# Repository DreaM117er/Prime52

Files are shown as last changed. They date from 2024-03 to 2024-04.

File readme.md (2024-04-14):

# Prime52 v1

- 中文說明（Chinese Readme）。
- [英文說明（English Readme）](readme_en.md)。

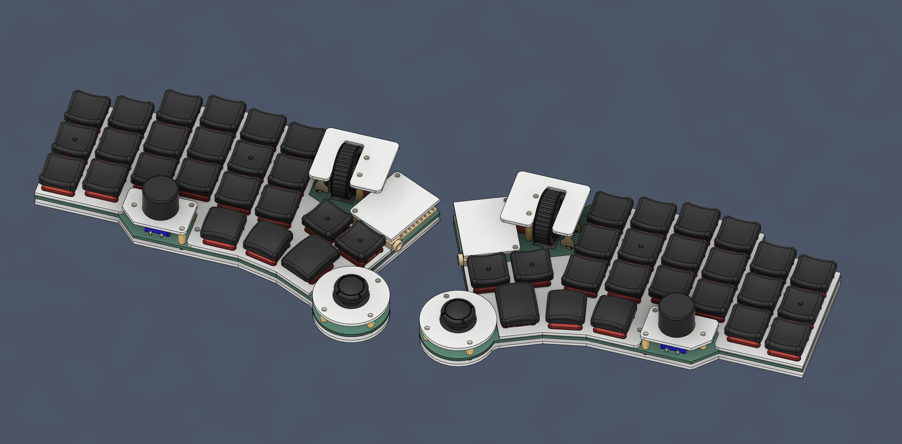
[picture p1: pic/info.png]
info
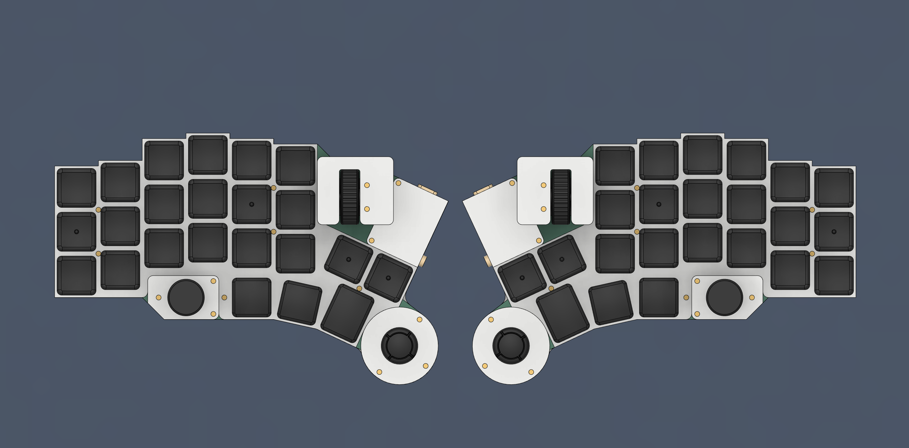
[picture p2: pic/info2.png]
info
|||
|--|--|
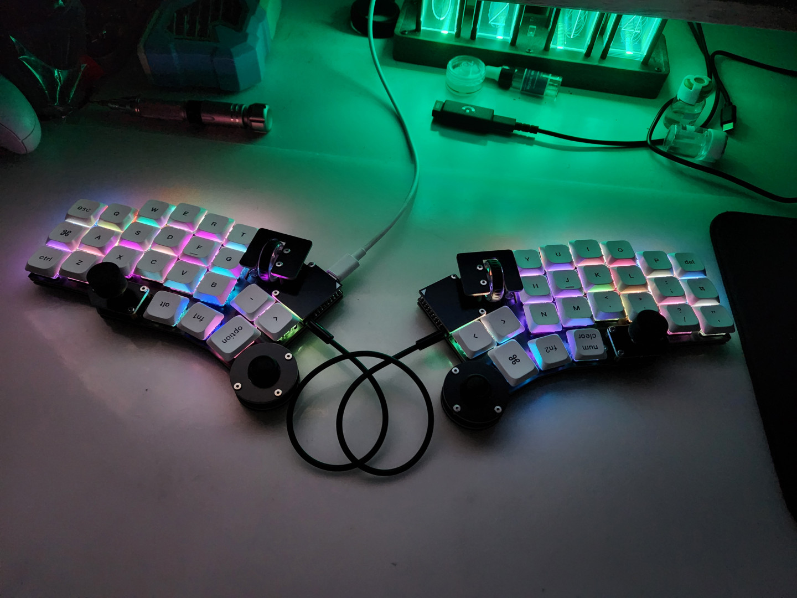
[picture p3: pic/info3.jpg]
info
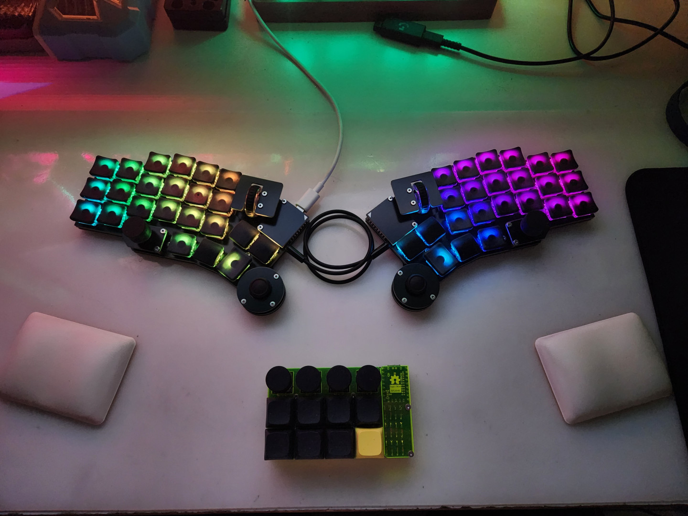
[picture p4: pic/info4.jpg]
info
|||

## 詳細說明

一直到現在為止，我還是無法適應軌跡球...

我個人沒有辦法去適應軌跡球的移動模式，更不用說要用什麼方式去操作它，因此在我將探索者1號設計出來的當下，我就知道還有一個將遊戲搖桿（Joystick）加進鍵盤內的構想在，也確實也有不少前輩設計出來，比如Dactyl Manuform Skeleton Edition的完整STL模型中，就有搖桿的存在。但礙於當時的我沒有足夠地了解3D建模及QMK韌體，一直到現在才有能力將這個很久以前就一直深埋在內心的夢想付諸實行。

它叫做Prime52，很簡單直接地說，它就是搭載Joy-con搖桿、EC-11旋轉編碼器及滑鼠滾輪的一把矮軸鍵盤，支援Choc v1、v2熱插拔。

## 使用材料

|名稱|數量|備註|連結|
|--|--|--|--|
|PCB|1|左、右|-|
|FR4外殼|2|含擋板|-|
|`RP2040Supermini`|2|-|[Link](https://www.aliexpress.com/item/1005006096780891.html?channel=twinner)|
|`EC-11`旋鈕編碼器|2|高`15mm`|[Link](https://www.aliexpress.com/item/1005006104167148.html?channel=twinner)| 
|`EC-11`編碼器帽蓋|2|`可選配`，有提供3D模型|-|
|`EC10E`滑鼠編碼器|2|高`11mm`|[Link](https://www.aliexpress.com/item/1005006279296138.html?channel=twinner)|
|`MR-0017`滑鼠滾輪|2|`可選配`，有提供3D模型|[Link](https://www.aliexpress.com/item/1005005878223914.html?channel=twinner)|
|`Joy-con`搖桿|2|`6pin`直插式|[Link](https://vi.aliexpress.com/item/1005006061159473.html)|
|`3.5mm` TRRS座|2|`4Pin`直插式|[Link](https://vi.aliexpress.com/item/1005003299392377.html?channel=twinner)|
|M2x`4mm` 雙通銅柱|12|定位板用|-|
|M2x`6mm` 雙通銅柱|6|搖桿用|-|
|M2x`7mm` 雙通銅柱|10|擋板用|-|
|M2x`15mm` 雙通銅柱|4|滑鼠滾輪用|-|
|M2x`3mm` 扁頭螺絲|48|-|-|
|M2x`8mm` 扁頭螺絲|16|-|-|
|`M2` 螺母|16|-|-|
|`M2` 防滑墊片|16||-|
|`ø8x1.5mm` 自黏腳貼|-|-|-|
|滑鼠用`微動開關`|2|-|[Link](https://vi.aliexpress.com/w/wholesale-mouse-switch.html?spm=a2g0o.productlist.search.0)|
|二極體 `1N4148`|52|貼片式 `SOD-123`|-|
|凱華`Choc`規格鍵軸|46|支援v1、v2|-|
|凱華`Choc`系列熱插拔座|46|-|[Link](https://vi.aliexpress.com/item/1005003879769486.html?channel=twinner)|
|`SK6212Mini-E` 反向LED燈|46|`選配`|[Link](https://vi.aliexpress.com/item/1005005956813491.html?channel=twinner)|

> **Note**
>
> 組裝鍵盤前務必先將韌體刷入MCU中，便測試及安裝方面會比較輕鬆容易：[點我進入組裝說明](guide.md)

## 現階段版本問題點

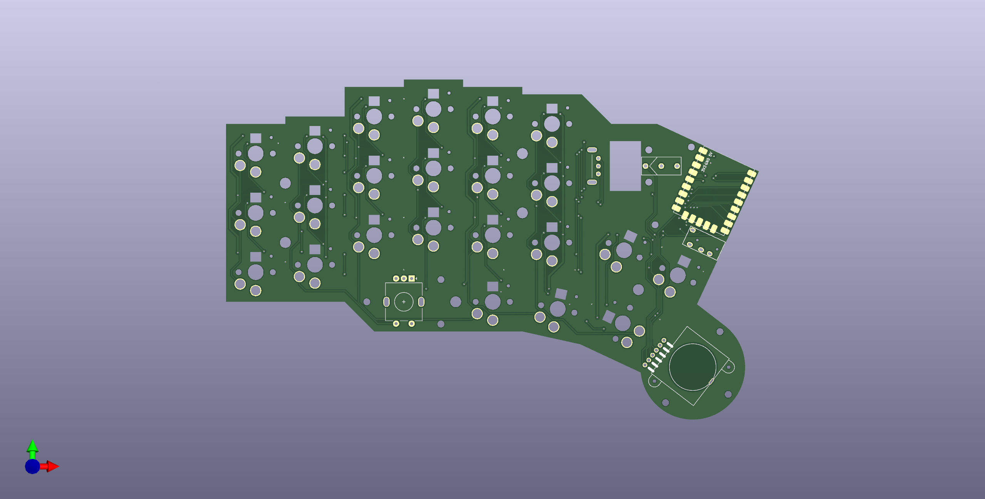
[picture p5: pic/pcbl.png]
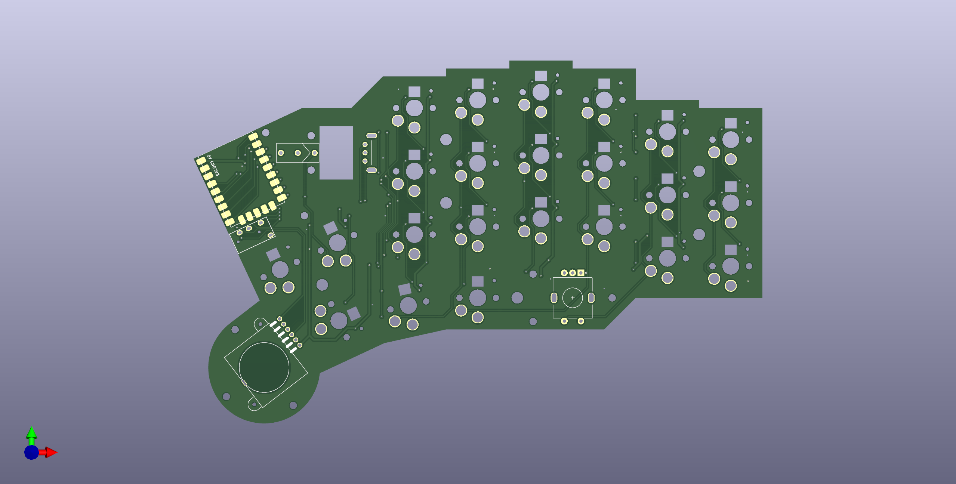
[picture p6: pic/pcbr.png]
|||
|--|--|
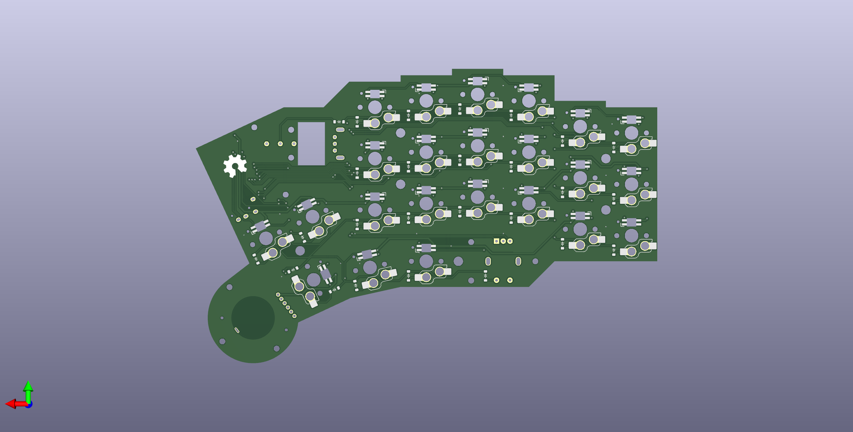
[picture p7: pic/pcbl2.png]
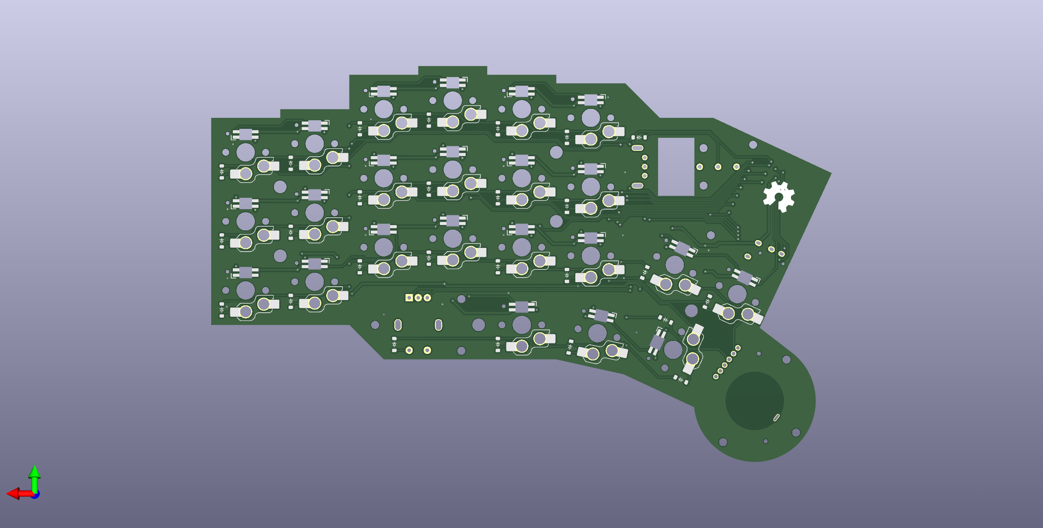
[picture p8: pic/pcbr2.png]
|||

- 滑鼠滾輪安裝上的困難，未來改進有無按鍵雙支援。
- 滑鼠編碼器的脈衝問題（暫時無法解決）。
- MCU的侷限性，未來可以支援更多類型的MCU，往大眾常使用的為主。
- 電路板的走線問題，也是無法支援更多MCU的主因。
- Slave端搖桿電位漂移、LED燈訊號有時而不穩定，有可能會開發新的鍵盤直接改掉這些問題。
- 看似對稱，但無法設計成對稱（Joy-con搖桿的主因）。

這是實際到手的`v1`版本在組裝上遇到的問題，`v2`版本的PCB會解決這個問題，並且會開發`MX`及`GLP`的版本出來。

## 使用資源

- Datasheets from TTC, ALPS, Huano.
- [QMK Firmware](https://qmk.fm/).
- [VIAL](https://get.vial.today/).
- [KiCAD](https://www.kicad.org/) version `7.0.5.`
- [JLCPCB](https://jlcpcb.com/).
- [DeepL](https://www.deepl.com/translator).
- [AutoDesk Fusion](https://www.autodesk.com/products/fusion-360/free-trial).

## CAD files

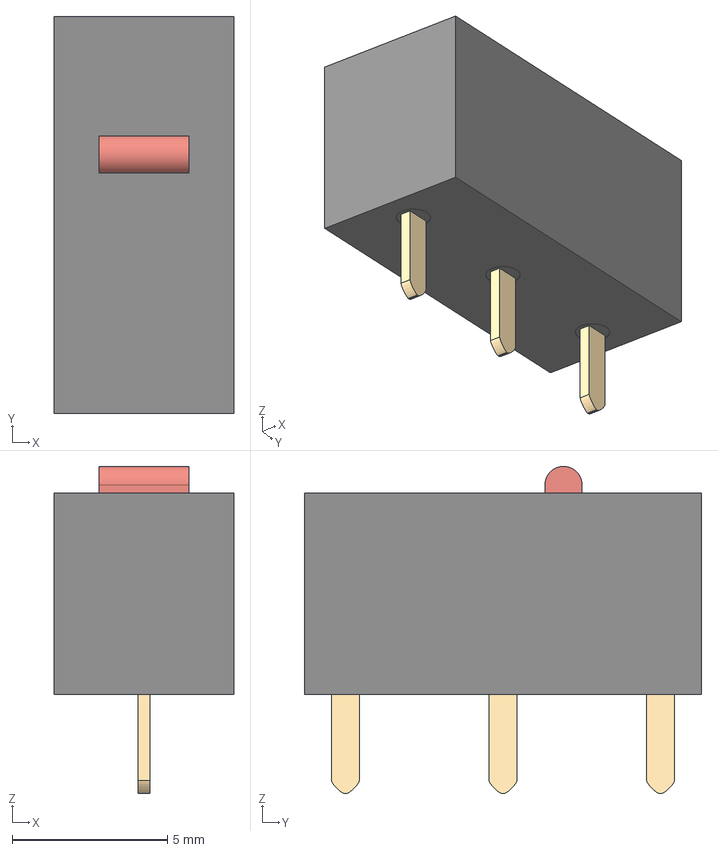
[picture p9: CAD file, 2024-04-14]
file/3d model/mouse micro switch.step
5.80 x 12.8 x 10.6 mm

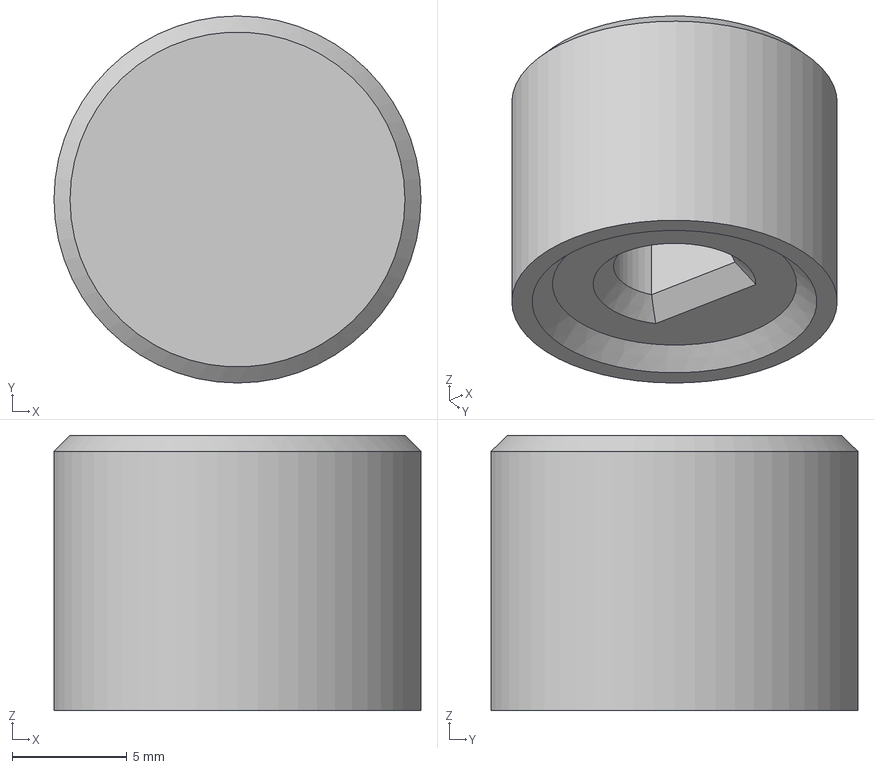
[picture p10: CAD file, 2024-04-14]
file/3d model/type-d h7.0mm.step
16.0 x 16.0 x 12.0 mm

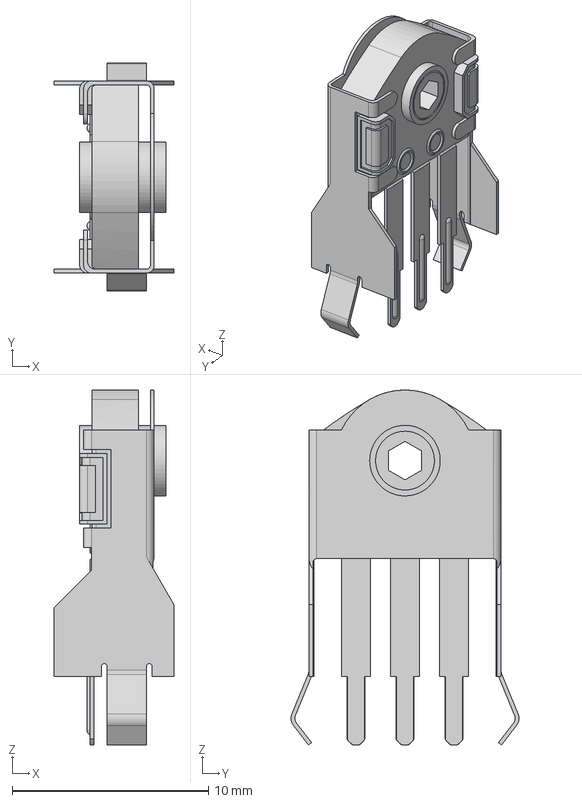
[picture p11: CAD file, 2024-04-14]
file/3d model/mouse encoder h11.step
6.10 x 11.6 x 18.1 mm

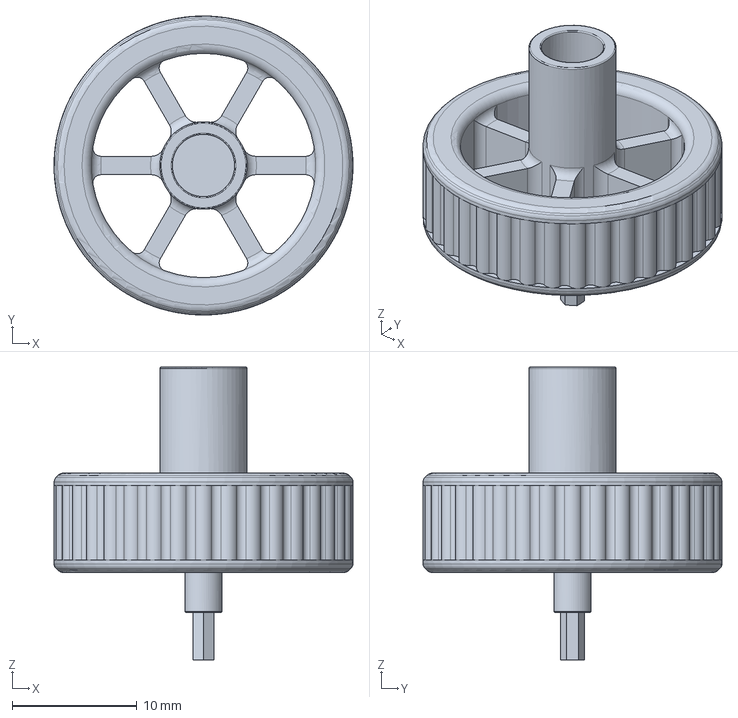
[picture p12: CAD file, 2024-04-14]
file/3d model/mousewheel MR0017 detail.step
24.0 x 24.0 x 23.5 mm

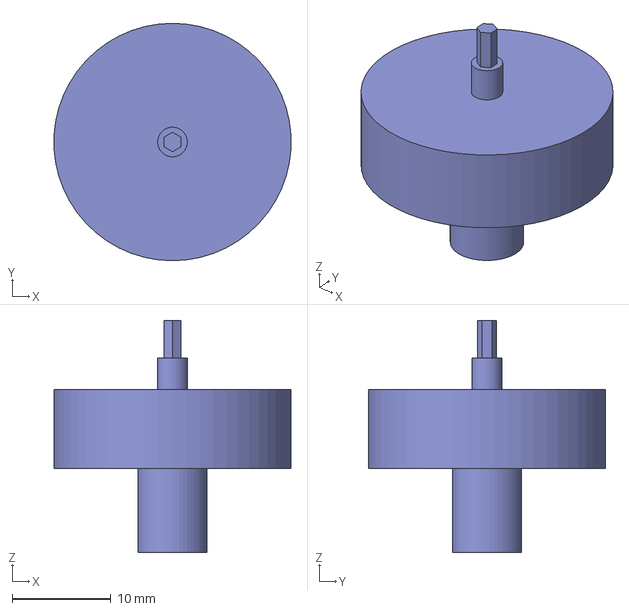
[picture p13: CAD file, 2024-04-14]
file/3d model/mousewheel MR0017 prototype.step
24.0 x 24.0 x 23.5 mm

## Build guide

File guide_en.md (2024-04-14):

# Building Guide

- [中文版本（Chinese Readme）](guide.md)。
- 英文版本（English Readme）。

## Firmware

> **Note**
>
> The firmware programming method of RP2040 series is more or less the same, no matter whether it is the version of MCU with Reset and Bootloader dual buttons or not, all of them have the same programming method.

- Press and hold the Bootloader button and then connect to the computer, the local computer will show you the location of the hard drive where the firmware is burned.
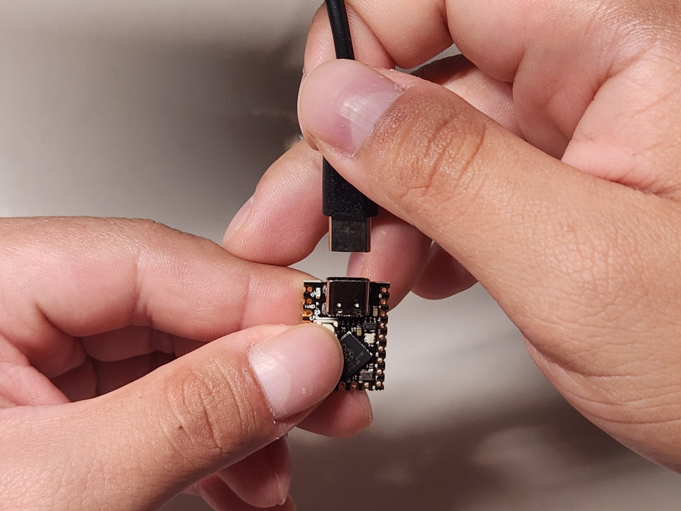
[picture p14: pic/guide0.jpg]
guide


- Then move the .uf2 firmware file to the hard drive to finish flashing.
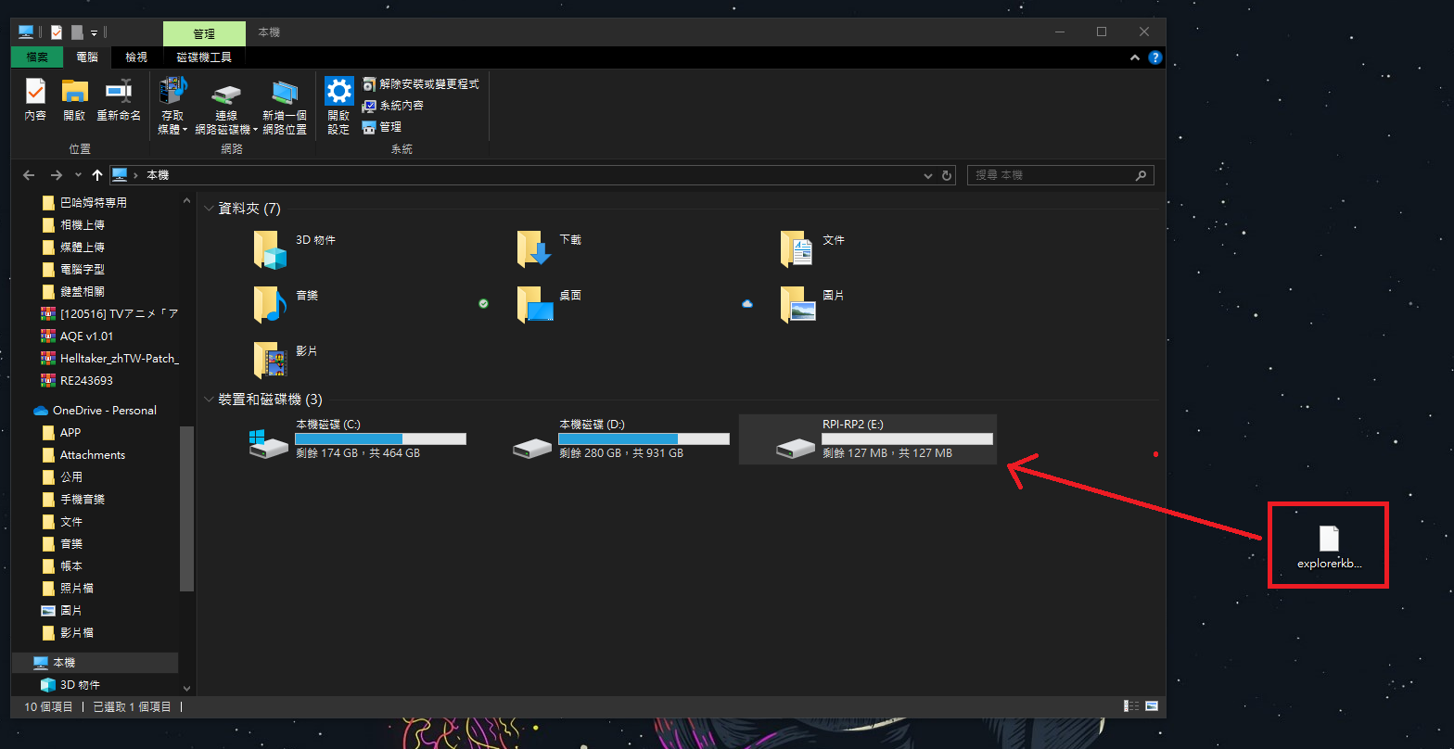
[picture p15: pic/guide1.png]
guide


## PCB and MCU

- First of all, prepare the two MCU and the left and right PCBs.
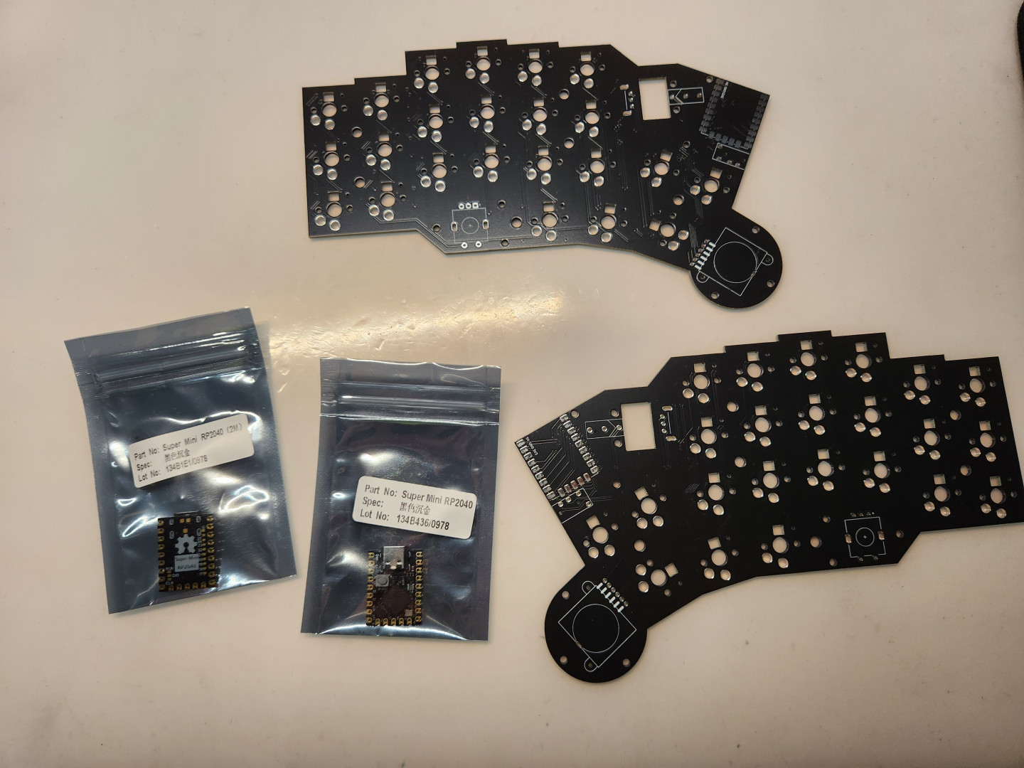
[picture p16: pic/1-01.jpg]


- Cut a piece of paper tape and fix the MCU with the tape in the right position.
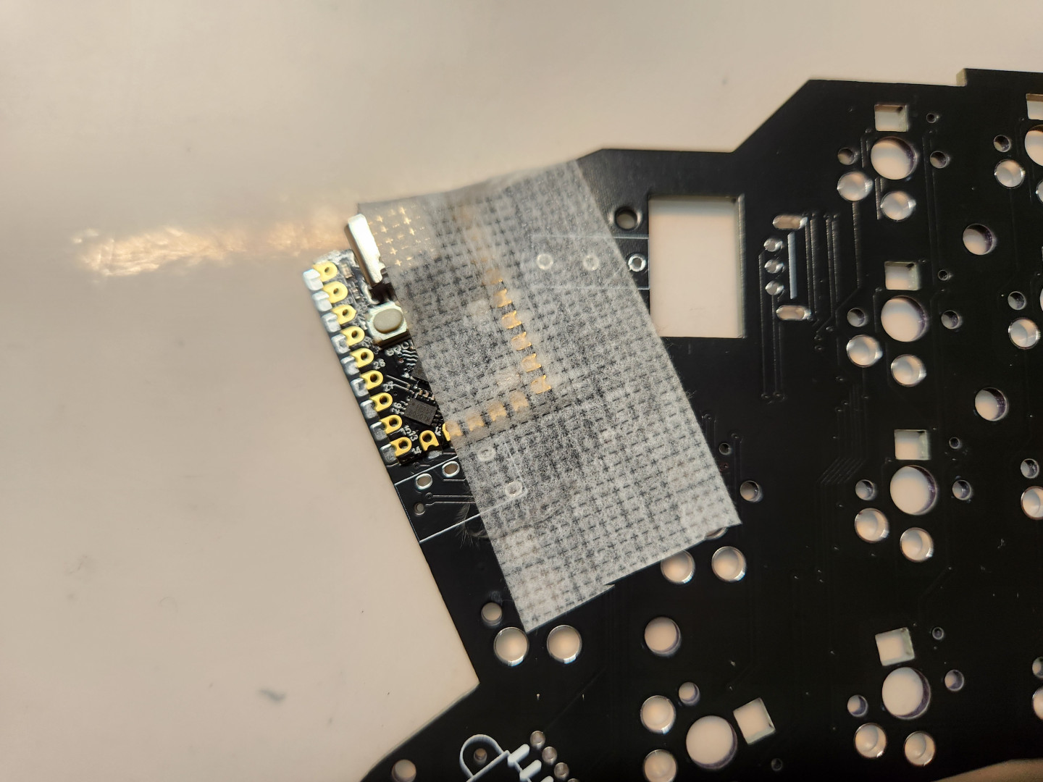
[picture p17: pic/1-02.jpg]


- Fix one of the rows of pads with solder first, and then tear off the tape.
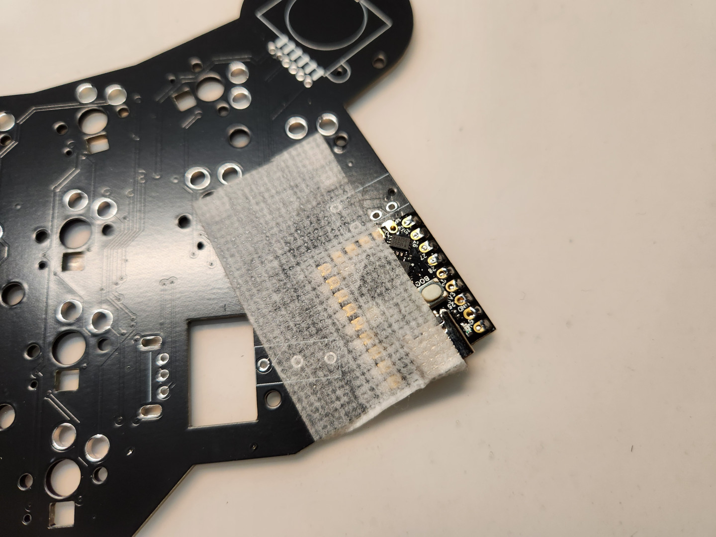
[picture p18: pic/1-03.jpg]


- Then use solder to attach the pads at the other locations.
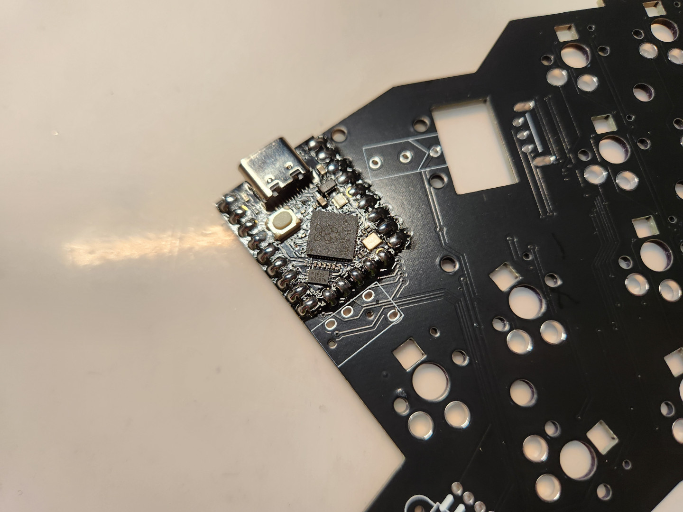
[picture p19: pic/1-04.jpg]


## SMD Parts

- Please refer to the picture for the mounting method of 1N4148 diode.
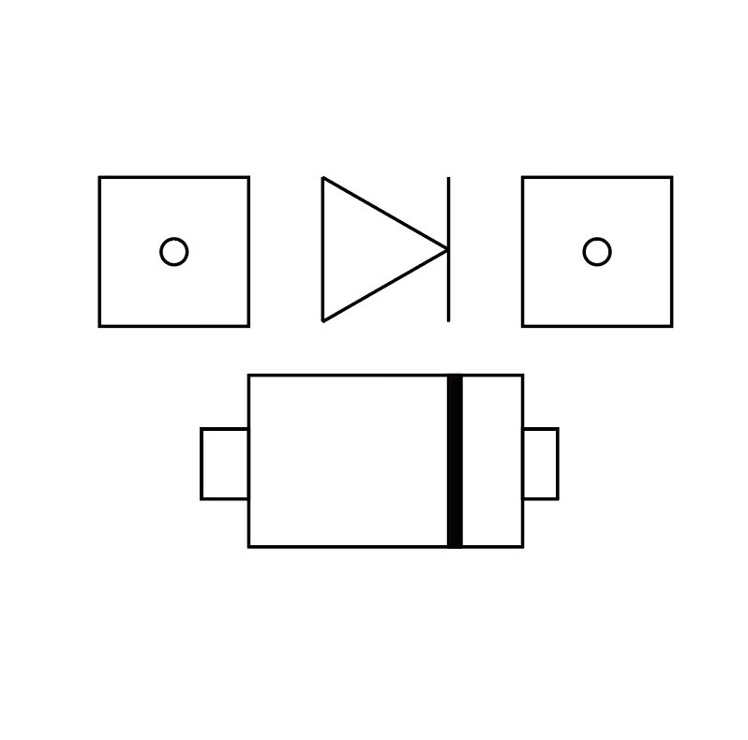
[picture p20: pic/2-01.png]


- Solder the 52 diodes together.
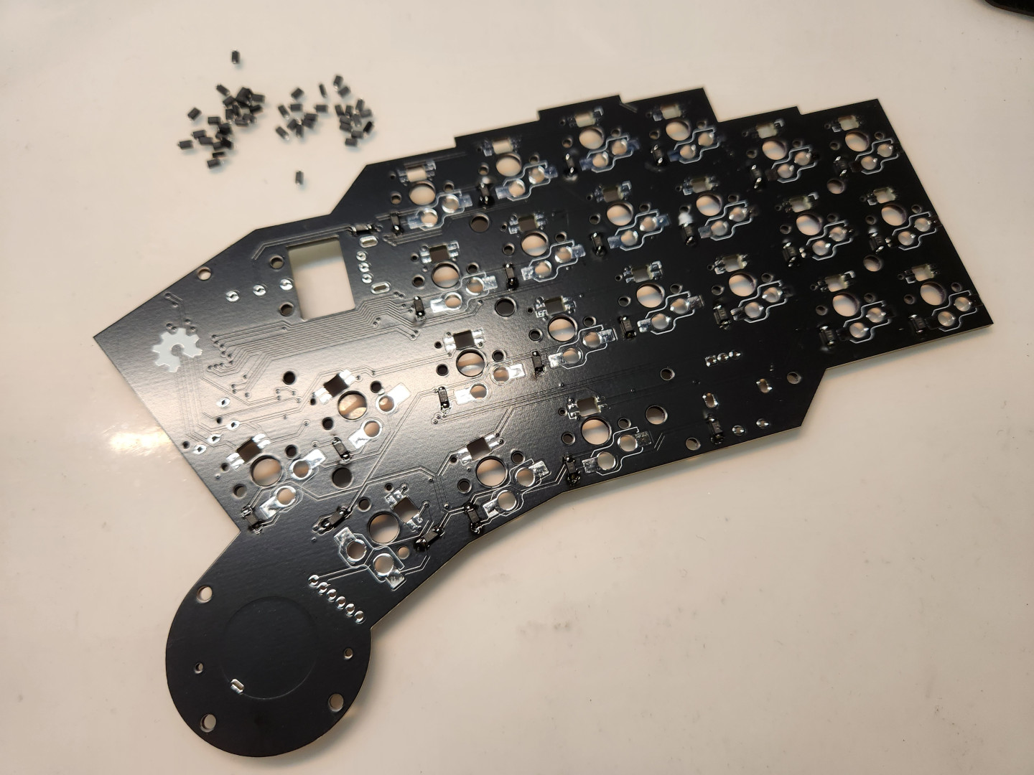
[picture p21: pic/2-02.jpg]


- The following photo shows how to install SK6812Mini-E, if you don't want to install LED lights, please skip this step.
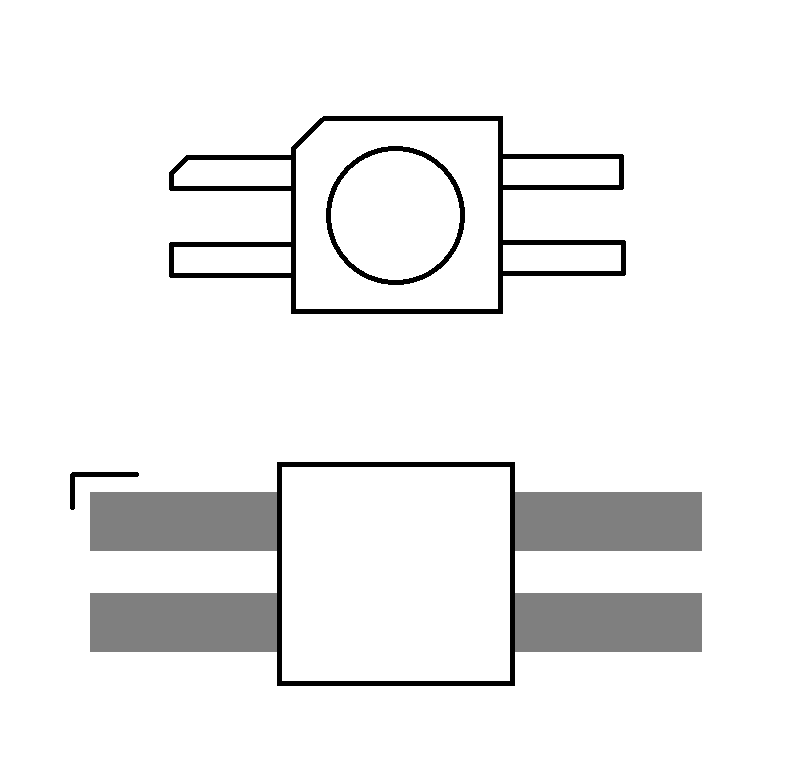
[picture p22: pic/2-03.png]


- Be careful not to leave the soldering iron on the soldering pad for too long, as the LEDs may be burnt out.
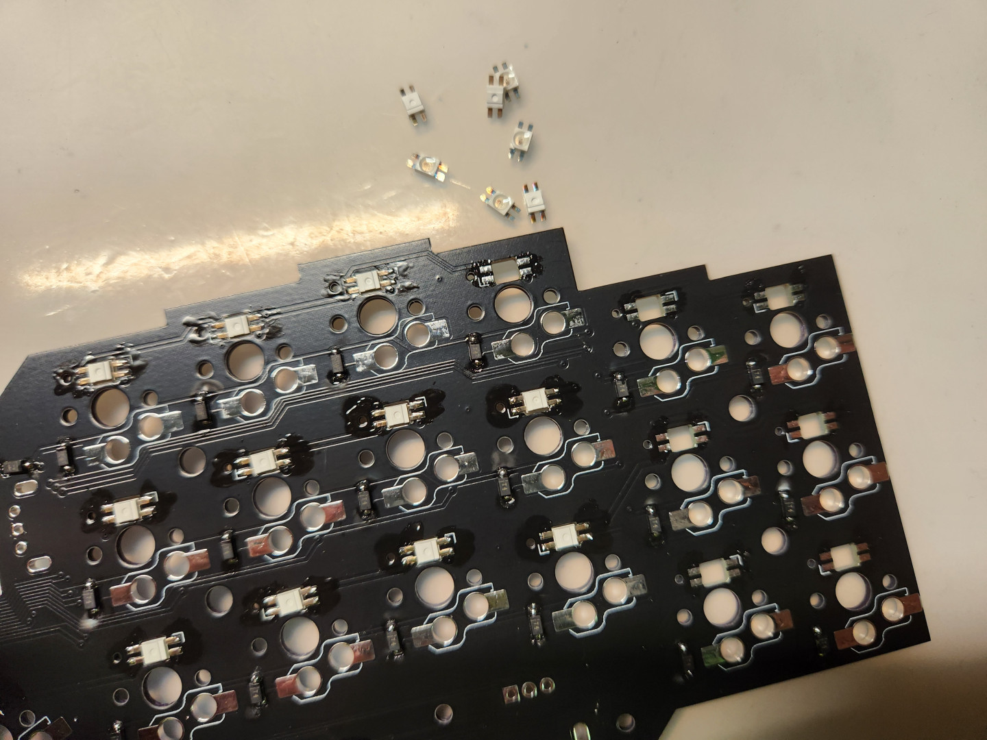
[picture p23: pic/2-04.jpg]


- After fixing the LED, you can connect it to the computer and test it, and the default light of the keyboard is on.
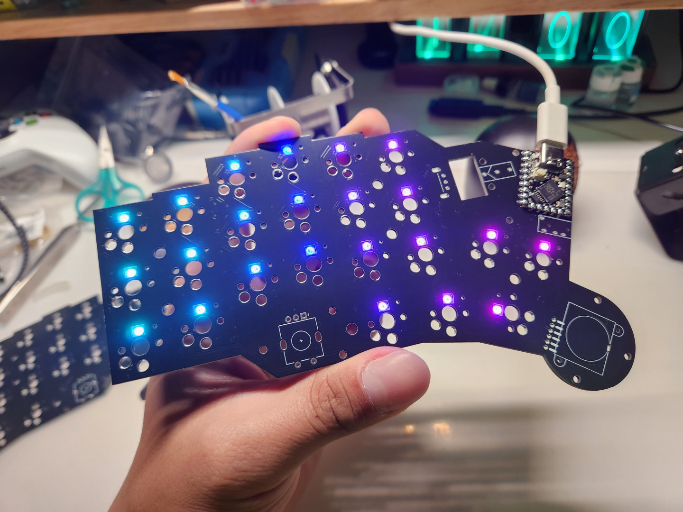
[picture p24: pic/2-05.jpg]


- After the diodes and LEDs are completed, the hot-swap sockets are finally attached to the board.
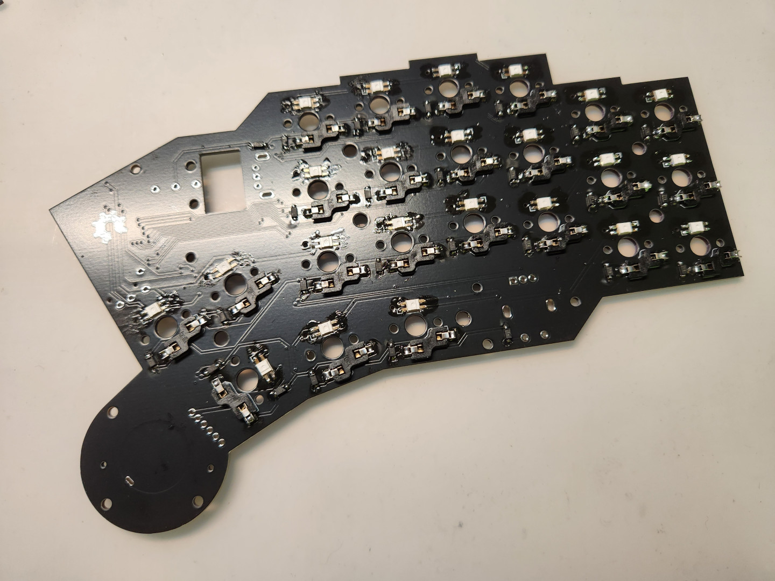
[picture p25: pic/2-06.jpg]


## Encoder and Jack

> **Warning**
>
> Due to a problem with this version, there is a difference in the way things are done here and in the photos, so please be sure to pay attention to the text.

- Prepare the Mouse Wheel, Mouse Microswitch, Mouse Encoder, Rotary Encoder, TRRS Holder, and Joy-con Joystick, and secure them to the PCB.
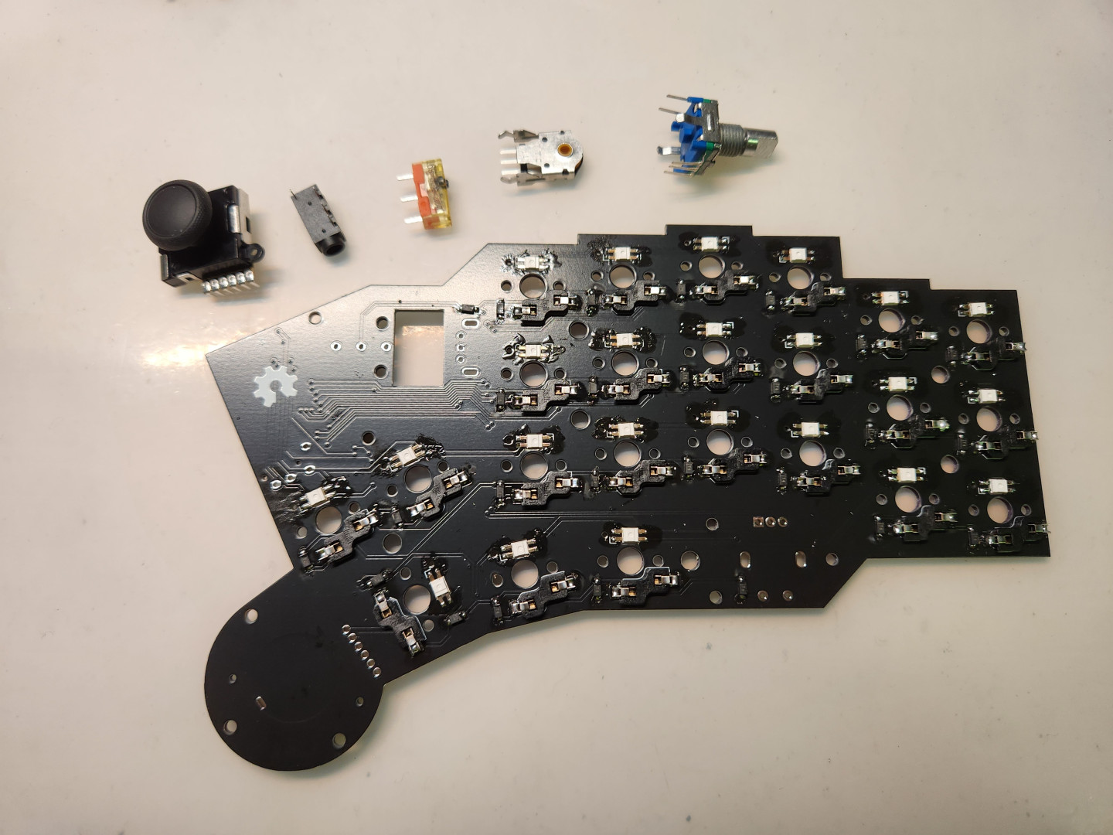
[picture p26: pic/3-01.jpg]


- The first step is to solder the mouse encoder in place and then attach the mouse wheel to the hexagonal wheel.
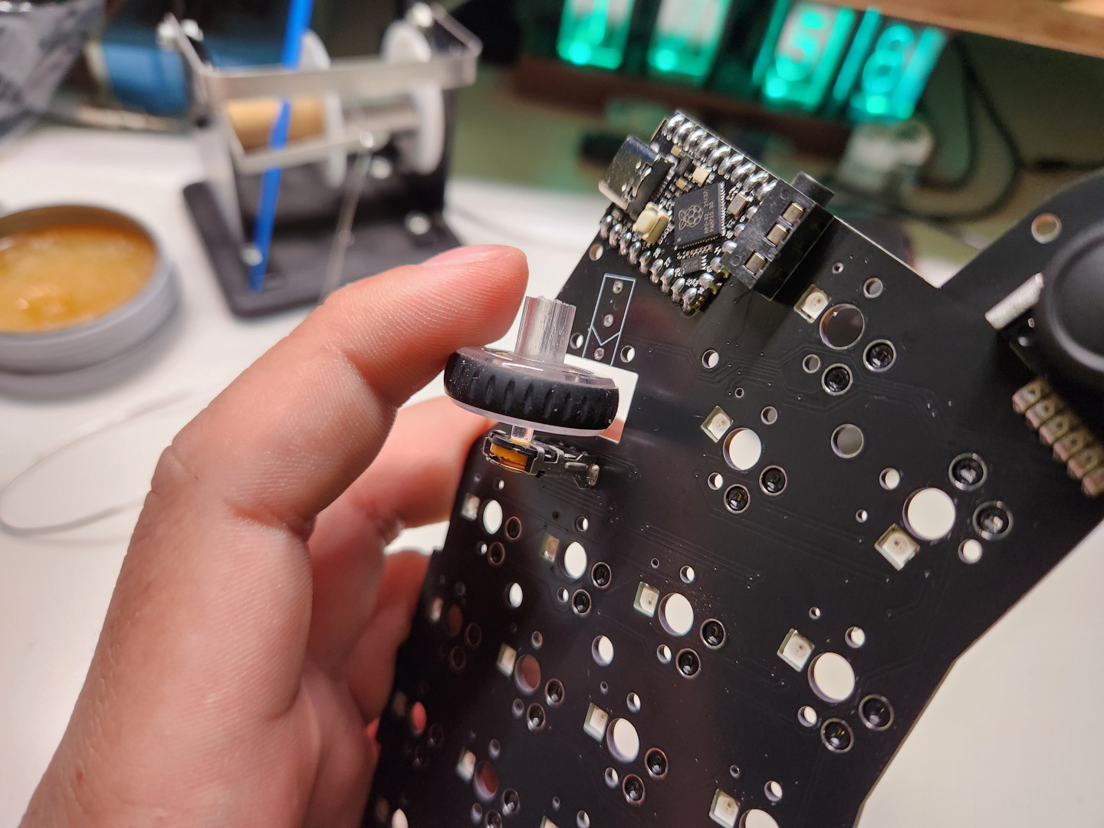
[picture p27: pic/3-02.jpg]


- Then weld the mouse microswitch in place at the pads.
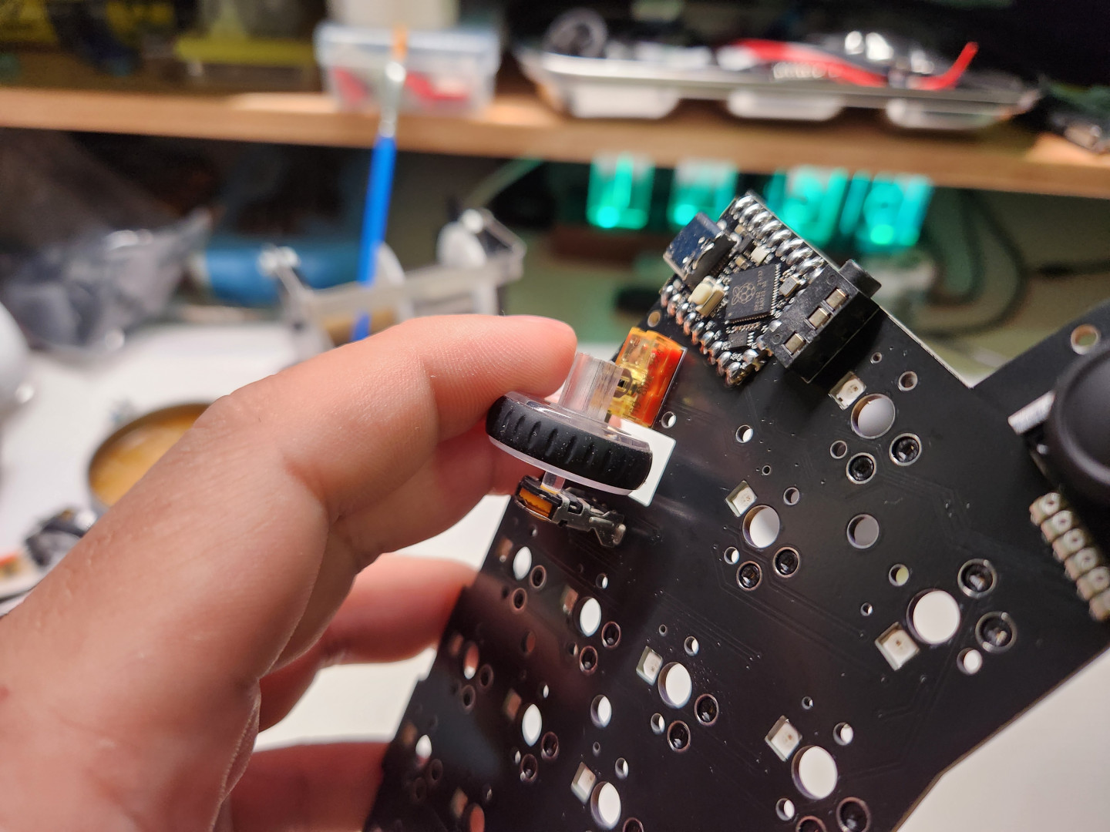
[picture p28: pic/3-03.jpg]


> **Note**
>
> If you don't do this first, the mouse wheel will not be properly installed on the encoder, so be careful.

- Solder the rotary encoder, TRRS holders, and Joy-con joystick as well.
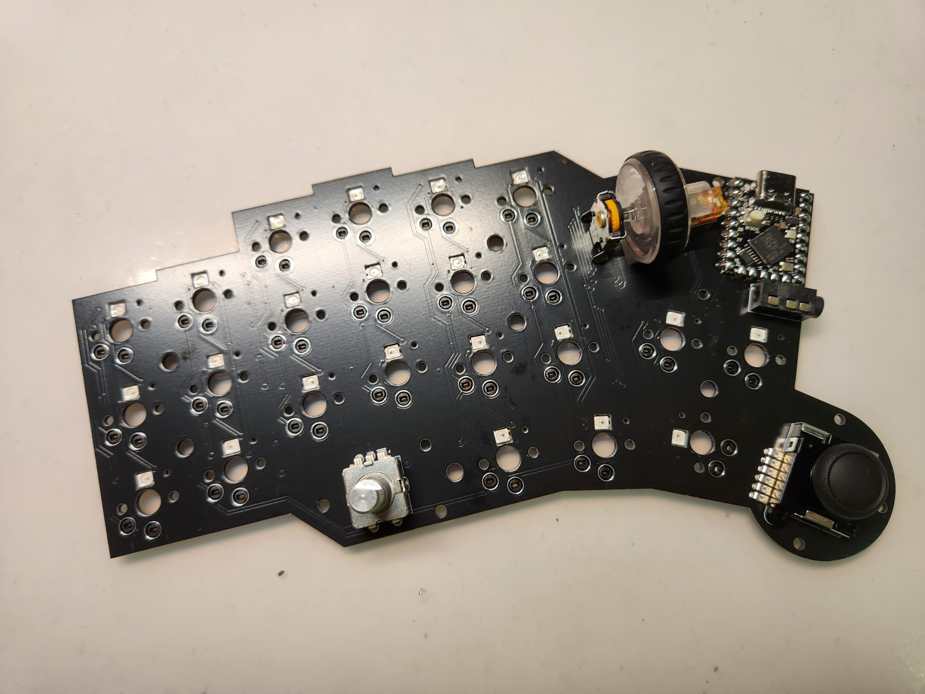
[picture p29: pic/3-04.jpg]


- Then you can test the power on the left and right side of the keyboard, be sure to test the LEDs and the signals of the left and right keyboard keys at this time. (The photo is a schematic picture, the whole installation is not finished.)
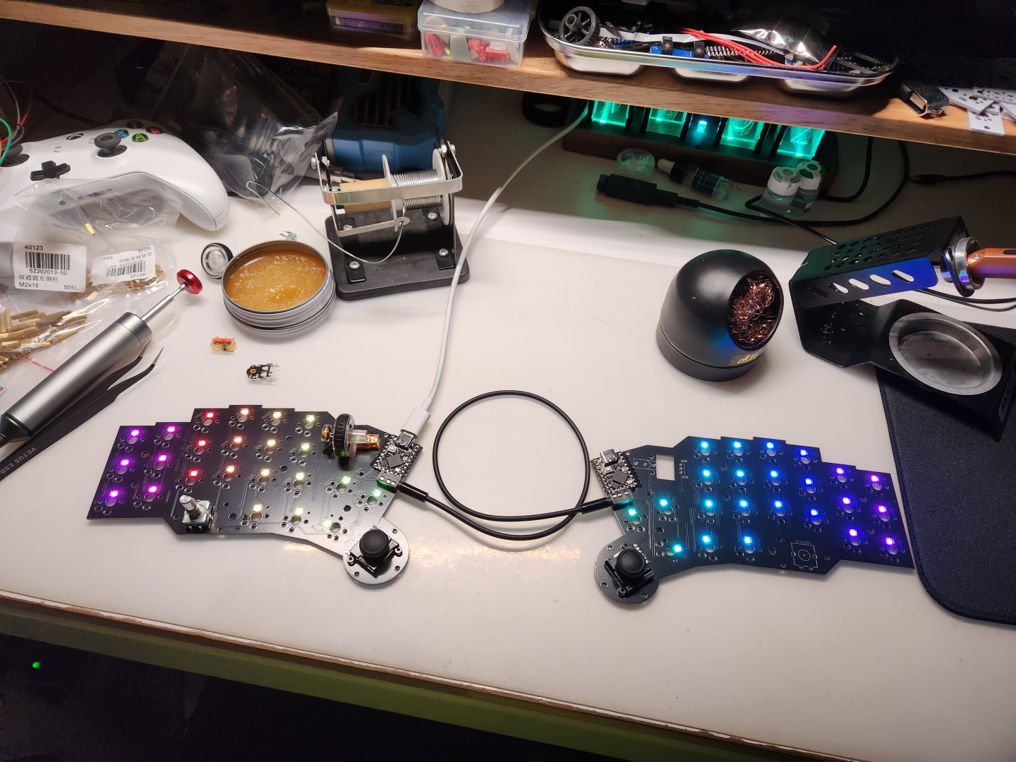
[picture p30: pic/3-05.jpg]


## Keyboard Building

- Prepare the 15mm spacers and 3mm screws, and install the post that holds the mouse wheel in place.
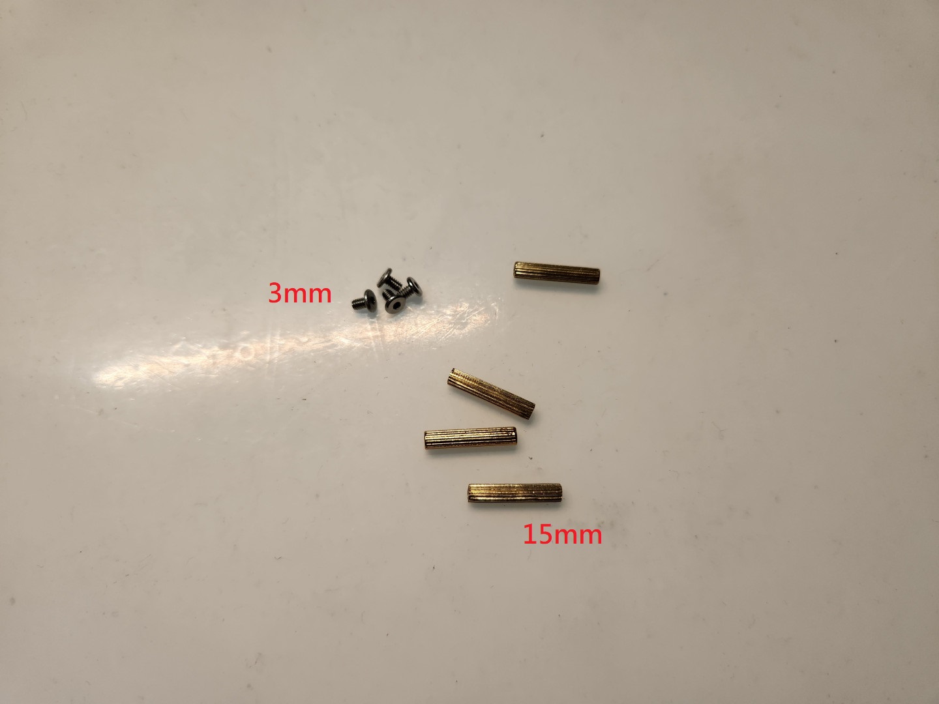
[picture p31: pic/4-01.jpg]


- Attach the spacers posts from the back of the left and right hand PCBs. 
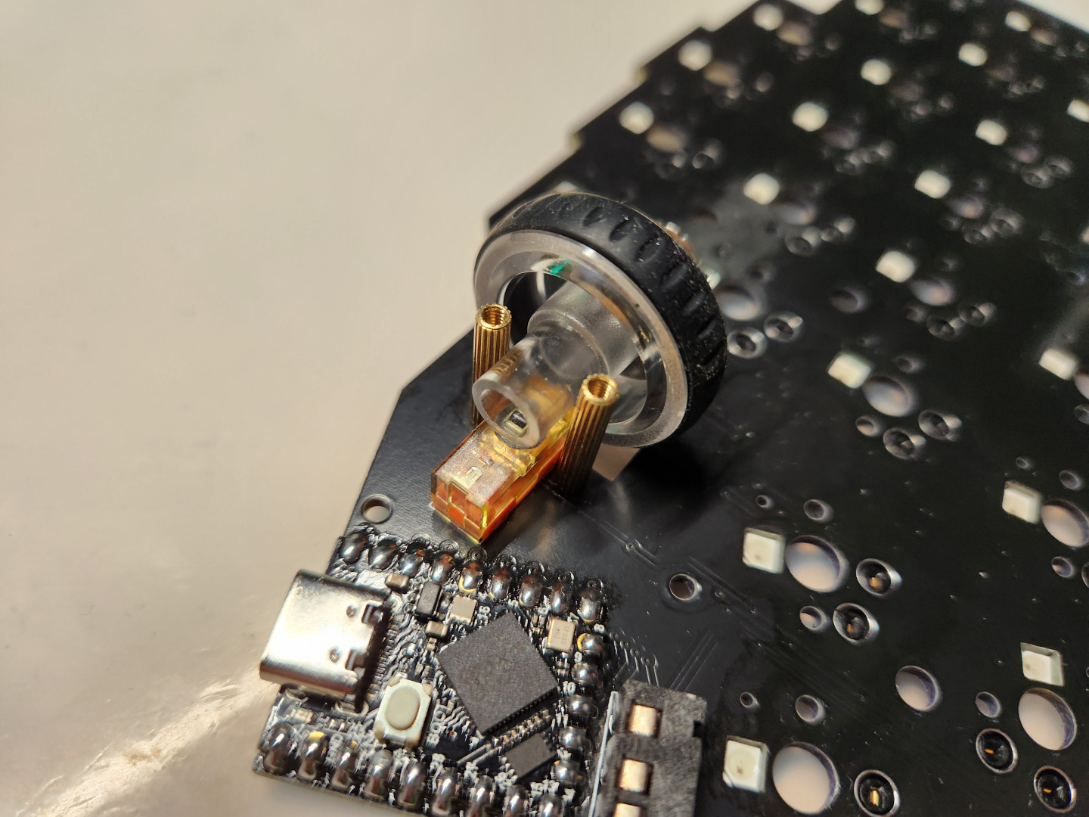
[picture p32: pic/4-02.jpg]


- Prepare 8mm screws, M2 nuts and M2 spacers, and fix them to the left and right side of the bottom case in order.
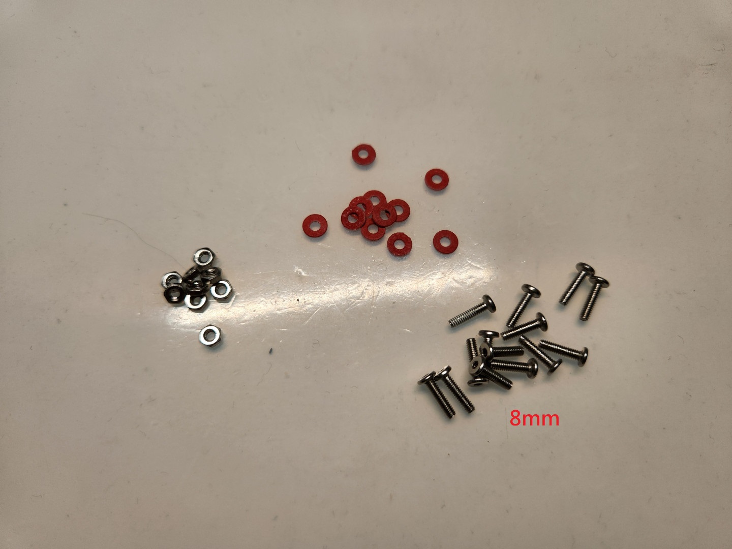
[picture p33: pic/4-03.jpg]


- Fix the 8mm screws on the left and right sides as shown in the photo.
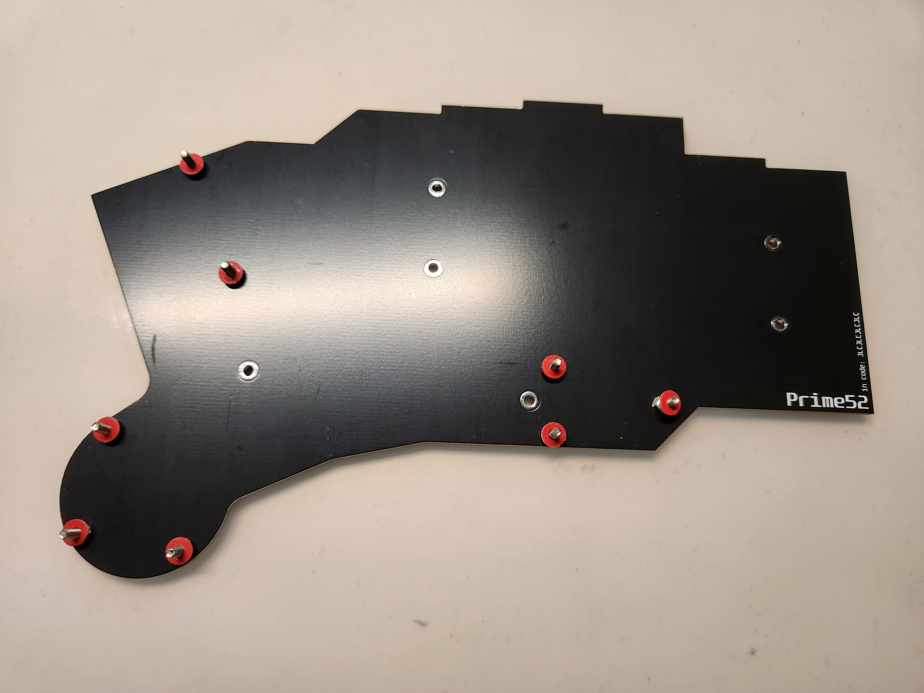
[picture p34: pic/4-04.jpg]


- Align the screw holes on the board and place the board on the base plate.
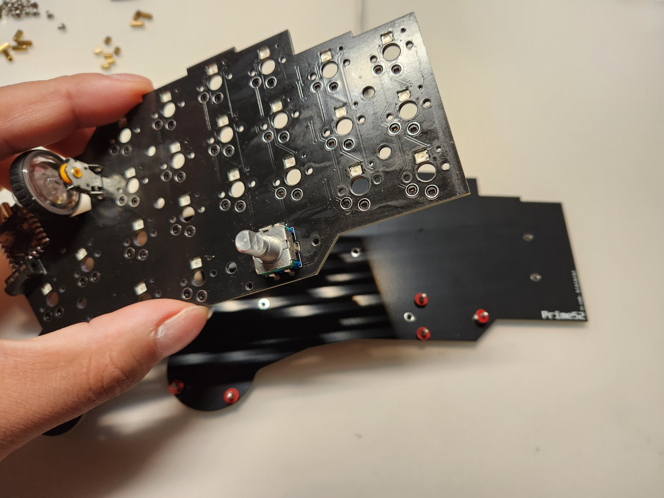
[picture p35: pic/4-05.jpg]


- Next, prepare 6mm and 7mm spacers.
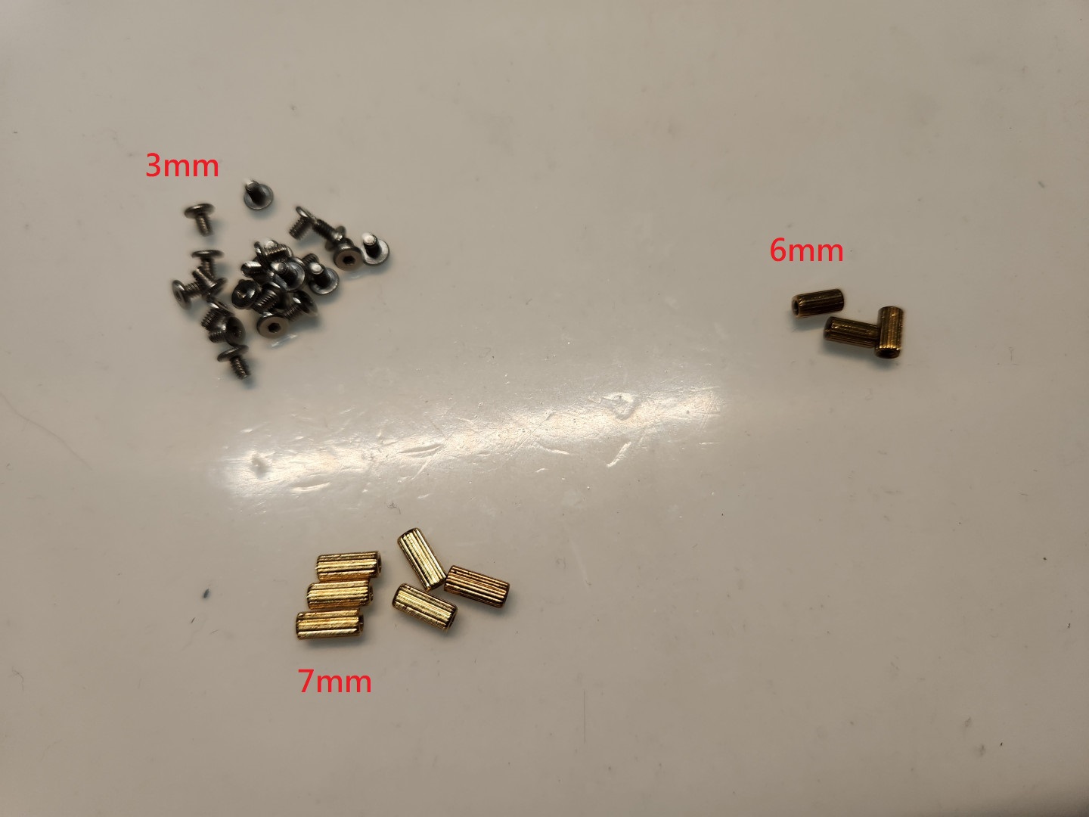
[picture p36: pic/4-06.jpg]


- 6mm brass post for Joy-con joystick, 7mm brass post for rotary encoder and MCU.。
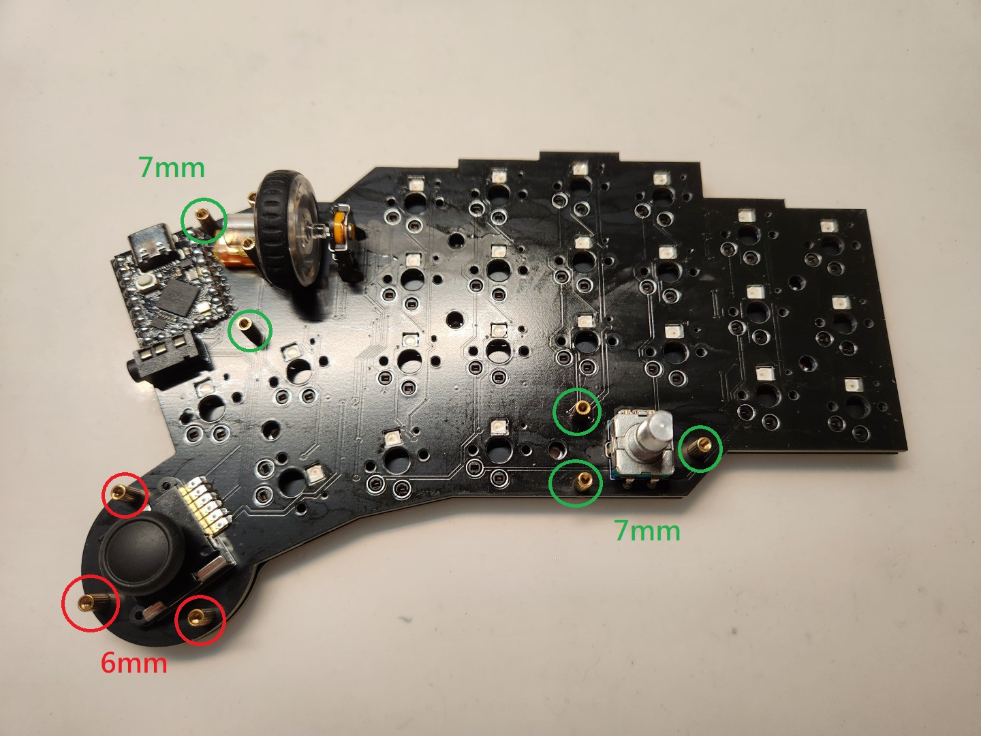
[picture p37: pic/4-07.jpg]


- Then prepare the positioning plate, 4mm spacers and 3mm screws.
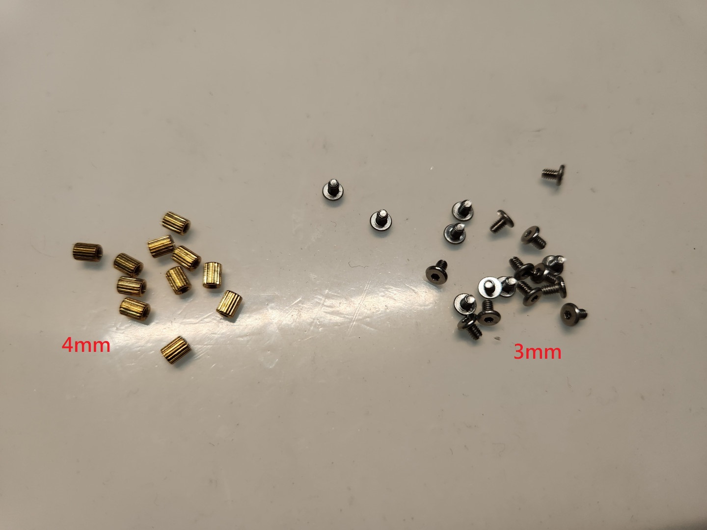
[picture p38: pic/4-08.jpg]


- Secure them to the screw holes in the plate.
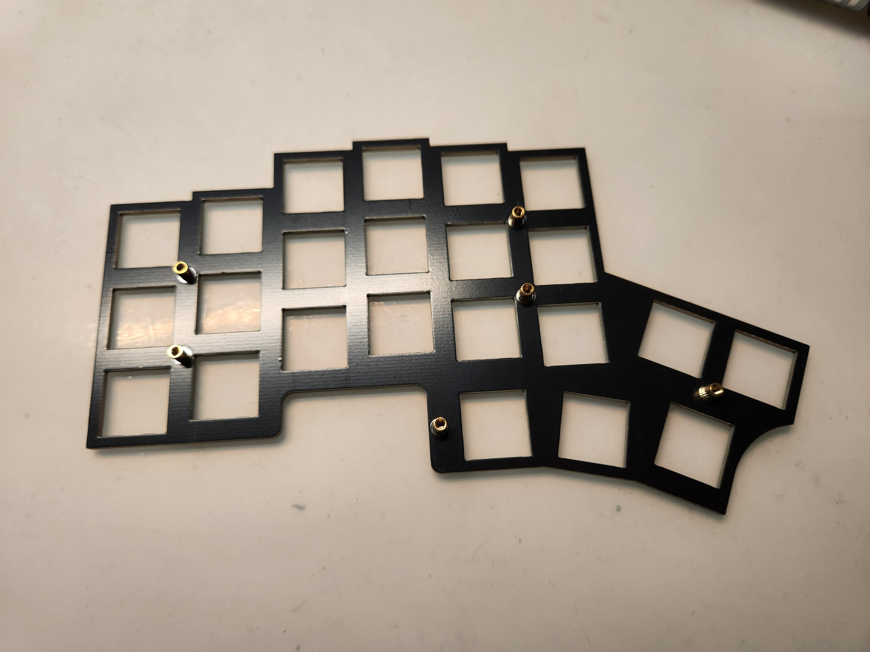
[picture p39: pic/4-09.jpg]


- Next, assemble the plate with the bottom case.
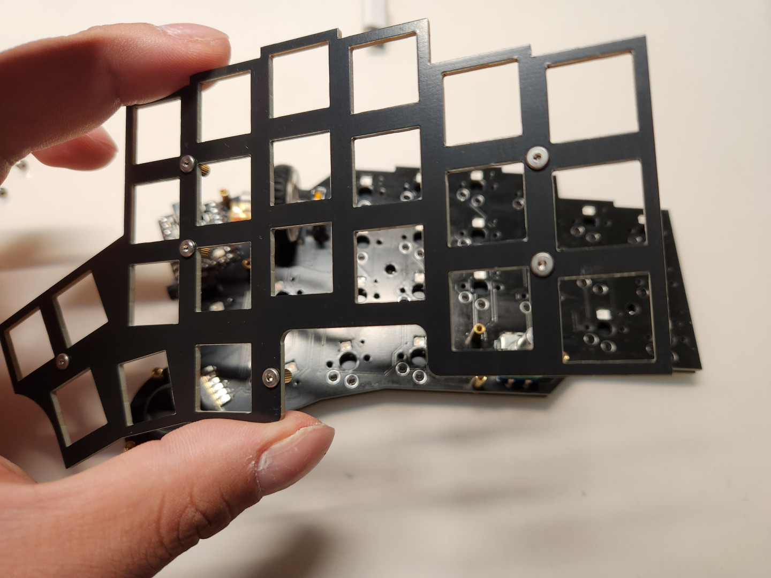
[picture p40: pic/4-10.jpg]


- Use 3mm screws to secure the locator plate from the back of the bottom case.
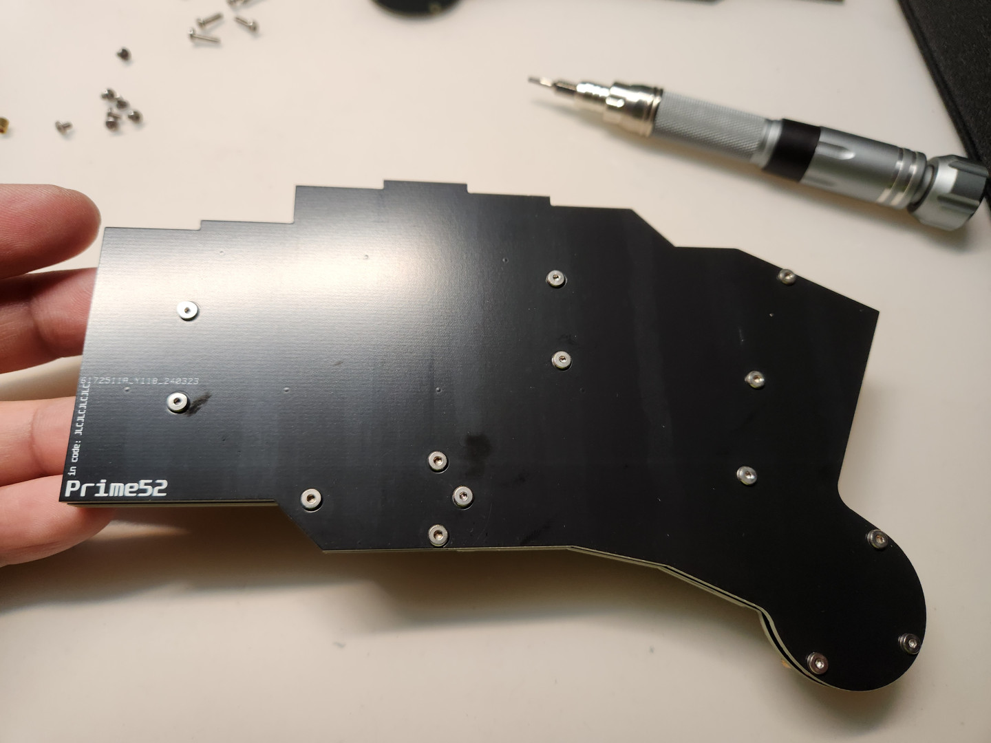
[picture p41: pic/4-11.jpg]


- The final step is to secure all the covers to the keyboard.
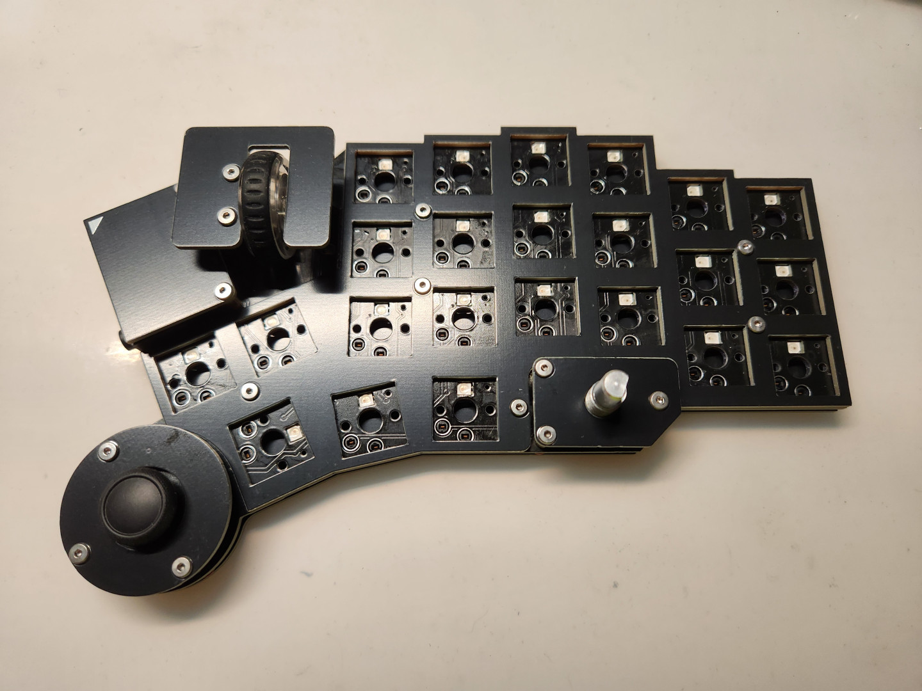
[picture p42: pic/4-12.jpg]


- When you're done, turn the keyboard over to the back and stick the rubber feet on it.
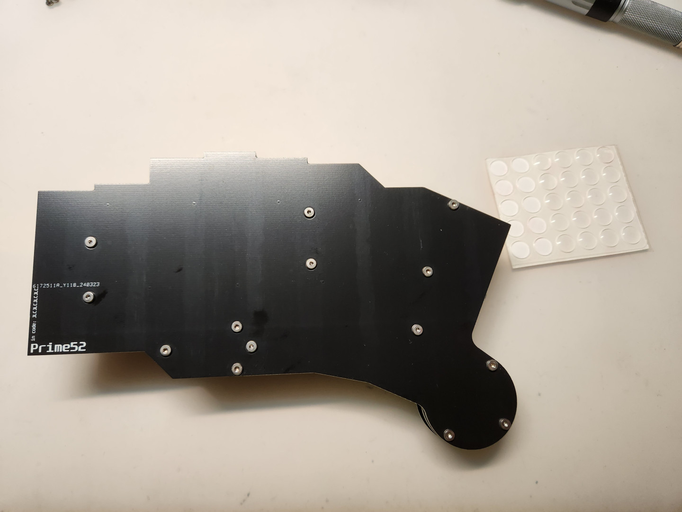
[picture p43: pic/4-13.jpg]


- Just paste it roughly like the picture below, and paste it more where it needs to be subjected to stronger force to make it more stable.
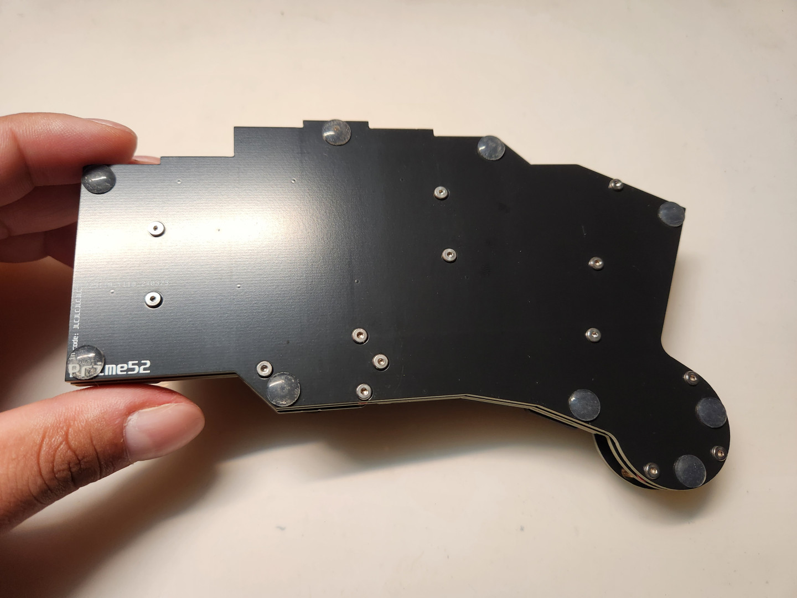
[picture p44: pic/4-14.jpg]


- Finish the two hands section and you're done.
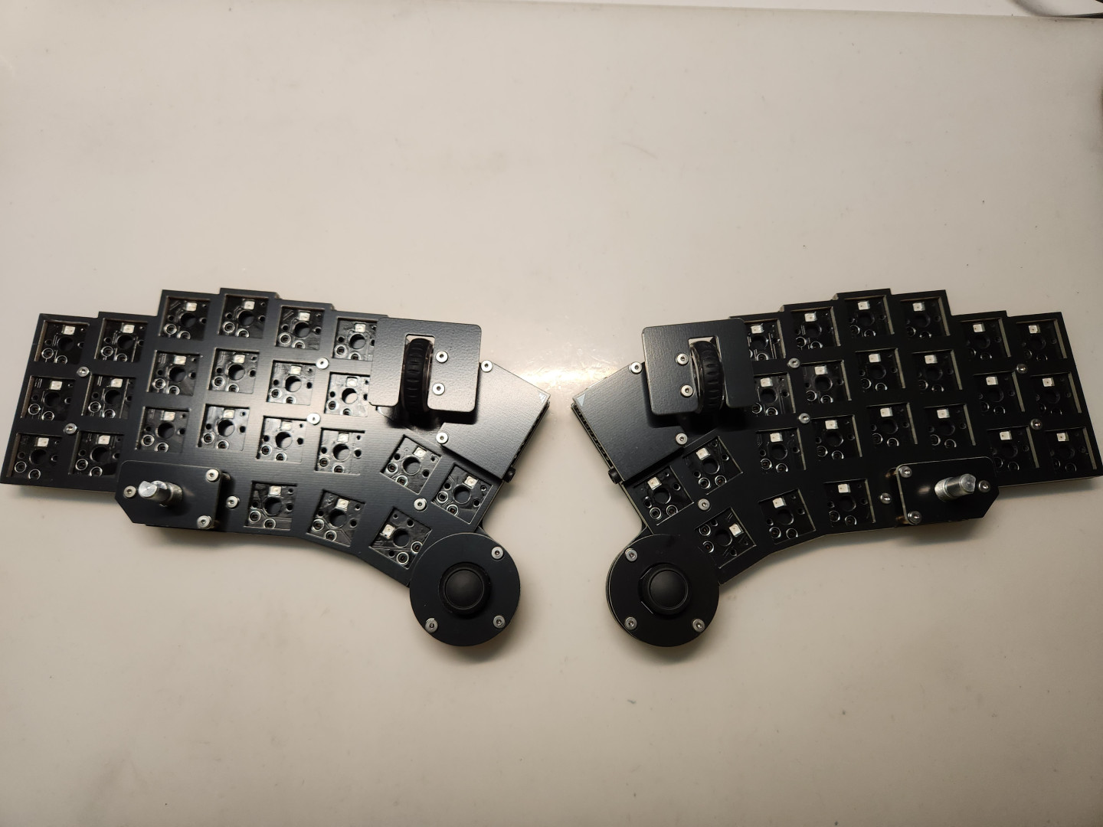
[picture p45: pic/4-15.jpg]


- install switches.
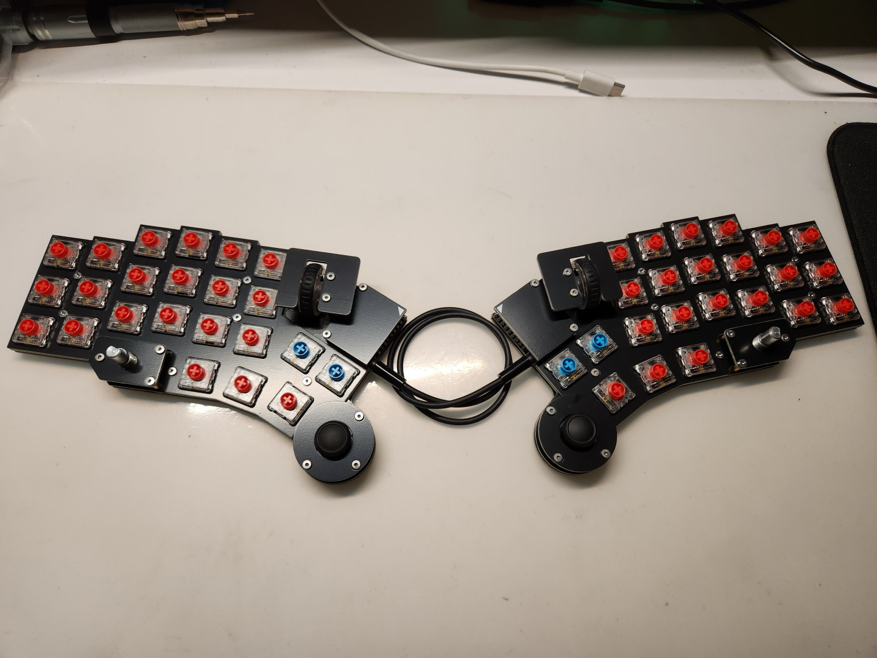
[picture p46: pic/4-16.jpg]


- Put on the keycap and test the lighting effect
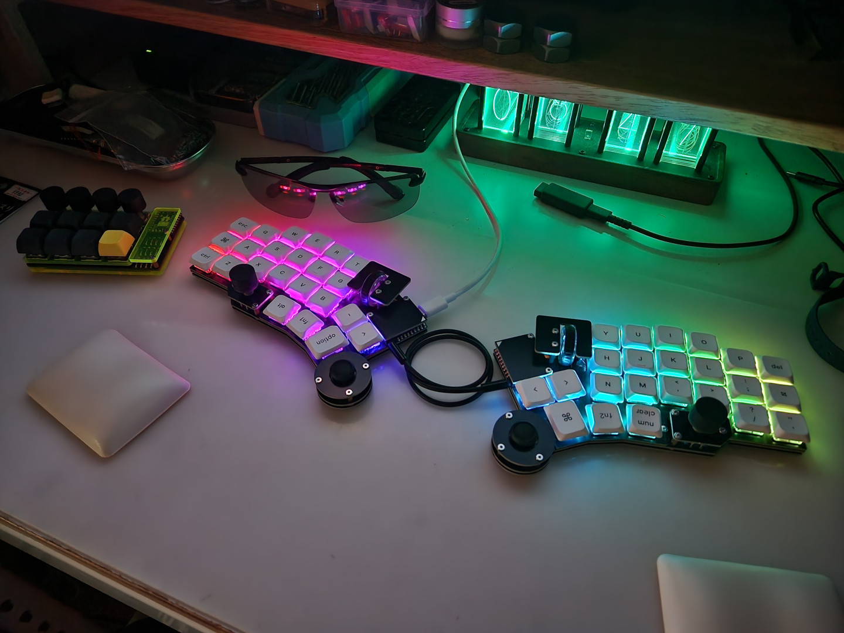
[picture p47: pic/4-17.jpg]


## Troubleshooting

- The LED light is on by default, if the LED light is not soldered and fixed completely, the light effect will run out, and in serious cases, the computer will not be able to recognise the keyboard, then try to turn off the light to exclude this problem directly, and then solder the LED to fix it well.
- If a single key does not trigger, please check in order: hot-swap socket, diode, switches.
- If a column/row does not trigger, please check to see if the MCU is not soldered properly.
- Don't forget to test the knobs and joysticks as they have their own keys.
- The test method of the encoder is to test the preset functions: volume up and down, scroll up and down.

I hope this can help you to solve any difficulties in the installation, thank you.

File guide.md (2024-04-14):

# 組裝說明

- 中文版本（Chinese Readme）。
- [英文版本（English Readme）](guide_en.md)。

## 韌體燒錄

> **Note**
>
> RP2040系列的韌體燒錄方式大同小異，不管是不是Reset、Bootloader雙按鈕的版本MCU，都有一個相同的燒錄方式。

- 按住Bootloader按鈕之後再接上電腦，電腦本機就會跳出燒錄韌體的硬碟位置。
guide

- 接著再將.uf2的韌體檔案移動至硬碟位置即可完成燒錄。
guide

## 電路板及主控板

- 首先將燒錄好韌體的2片主控板跟左右手電路板準備好。


- 接著剪下一段紙膠帶，對好位置把主控板用膠帶先固定好。


- 先將其中一排焊盤先用焊錫固定好，再將膠帶撕掉。


- 最後再用焊錫把其他位置的焊盤都焊上。


## 貼片元件

- 1N4148二極體的安裝方式請參照圖片所示。


- 接著將52個二極體用焊錫焊接好。


- 下圖是SK6812Mini-E的安裝方式，如果沒有要安裝LED燈的話，請跳過這個步驟。


- 貼片LED燈務必留意電烙鐵不要在焊盤上停留過久的時間，LED燈有機率會被燒壞。


- LED固定好之後可以先接上電腦測試，鍵盤預設燈亮。


- 二極體、LED燈都完成之後最後再將熱插拔座固定在電路板上。


## 編碼器及插座

> **Warning**
>
> 現階段版本問題的原因，這裡的做法會跟照片有所出入，請務必留意文字說明。

- 將滑鼠滾輪、滑鼠微動、滑鼠編碼器、旋鈕編碼器、TRRS座及Joy-con搖桿準備好，並依序將它們固定在電路板上。


- 第一步先將滑鼠編碼器焊接固定好之後，再把滑鼠滾輪固定在六角輪上。


- 接著再將滑鼠微動卡在定位點焊接固定好。


> **Note**
>
> 如果不先這麼做的話，滑鼠滾輪會無法正常安裝到編碼器上，務必留意。

- 接著再將旋鈕、TRRS座、Joy-con搖桿也都焊接起來。


- 然後就可以測試鍵盤左右側通電的狀況，務必在這個時候就進行LED燈測試及左右鍵盤按鍵的訊號狀況。（照片為示意圖，沒有完成整體的安裝）


## 鍵盤組裝

- 接著將15mm的銅柱、3mm的螺絲準備好，先來安裝固定滑鼠滾輪的銅柱。


- 從左右手的電路板背面將銅柱固定上去。 


- 接著準備8mm螺絲、M2螺帽及M2螺絲墊片，將它們依序固定在左右側的鍵盤底板上。


- 左右側按照照片示意固定8mm的螺絲。


- 對好電路板上的螺絲孔，將電路板放在底板上。


- 接著準備6mm、7mm銅柱。


- 6mm銅柱安裝在Joy-con搖桿的位置、7mm銅柱安裝在旋鈕編碼器及主控板的位置。


- 接著準備定位板、4mm銅柱及3mm螺絲。


- 把它們固定在定位板上的螺絲孔上。


- 接著把定位板跟底板組合在一起。


- 使用3mm螺絲從底板後面把定位板固定起來。


- 最後一步將所有的擋板固定到鍵盤上。


- 完成之後把鍵盤翻到背面，把自黏腳貼貼上去。


- 大致像下圖這樣貼即可，需要受較大力的地方多貼一些比較穩固。


- 將兩隻手的部分完工就結束了。


- 上軸。


- 上鍵帽，測試燈光效果。


## 疑難排解

- LED燈預設是開著燈，如果LED燈沒有焊接固定完整，燈效會跑掉，嚴重時電腦會無法辨識鍵盤，這時設法將燈光關閉可以直接排除這個問題，屆時再將LED焊接固定好即可。
- 如果單顆按鍵沒有觸發，請依序檢查：熱插拔座、二極體、鍵軸。
- 如果單排按鍵沒有觸發，請檢查看看是不是主控座沒有焊接好。
- 旋鈕及搖桿本身自帶按鍵，不要忘記測試。
- 編碼器的測試方式即測試預設的功能：音量大小、滾輪上下滾動。

希望這個能夠幫助大家解決任何在安裝上的困難，謝謝大家。

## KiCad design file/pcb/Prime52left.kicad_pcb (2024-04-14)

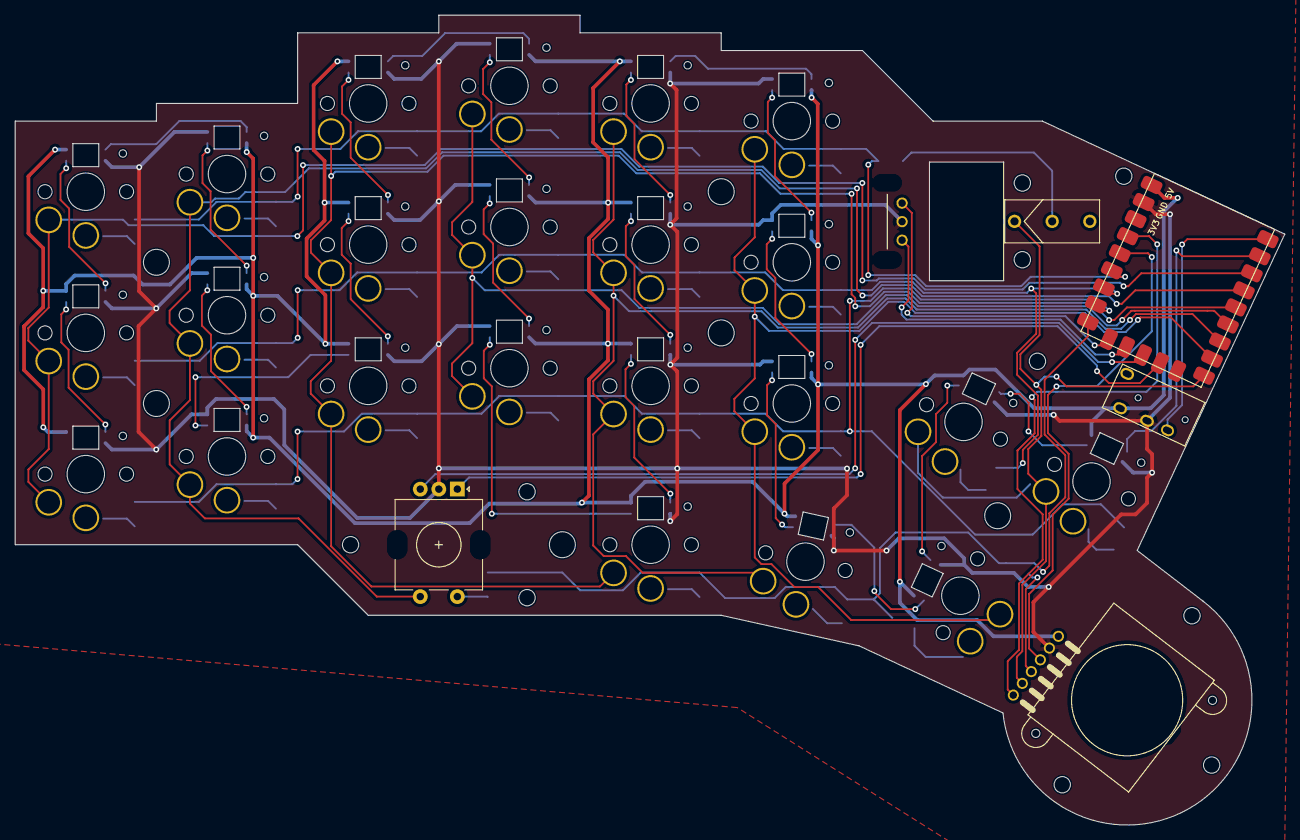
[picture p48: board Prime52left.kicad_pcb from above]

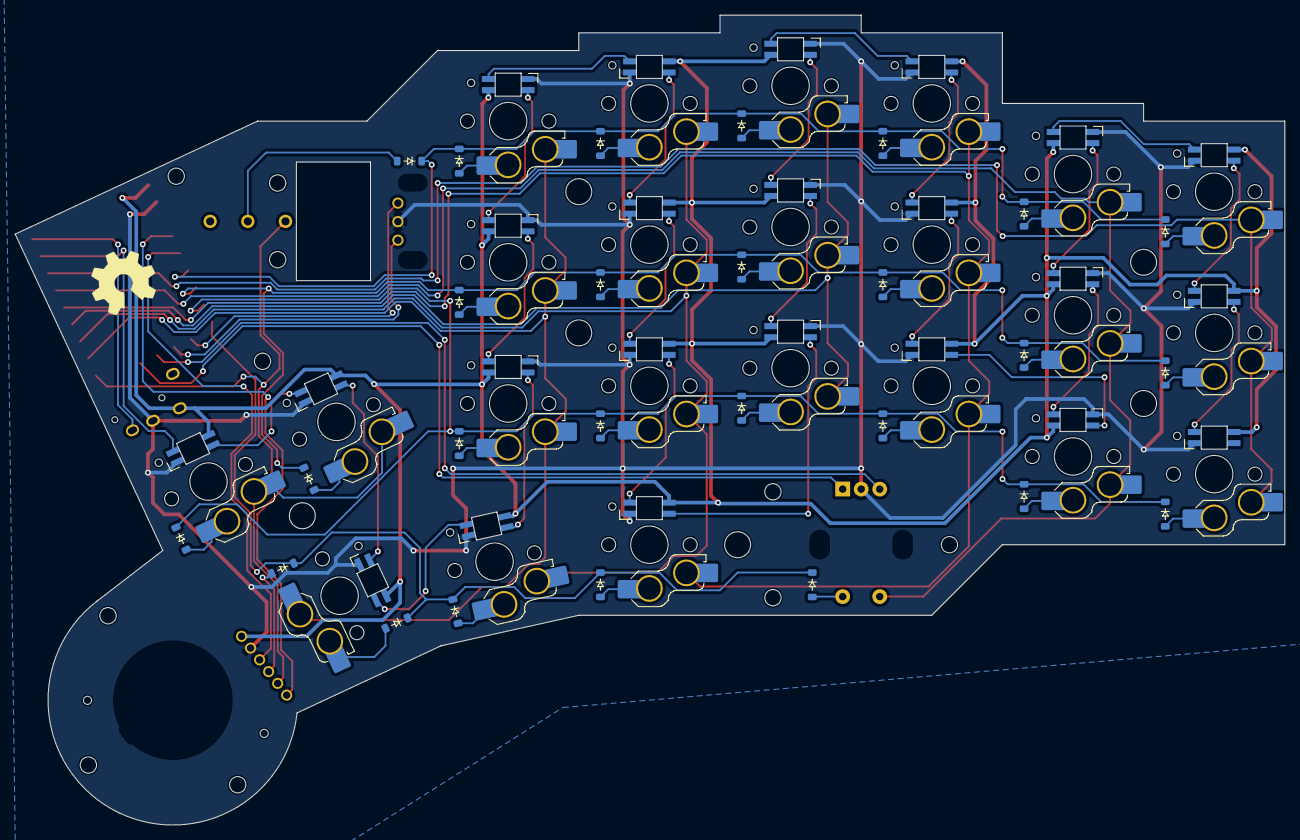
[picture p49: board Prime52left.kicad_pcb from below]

Board: 2 copper layers, 171.3 x 109.3 mm, 88 parts (50 on the bottom side), 69 nets.

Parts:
D1, D2, D3, D4, D5, D6, D7, D8, D9, D10, D11, D12, D13, D14, D15, D16, D17, D18, D19, D20, D21, D22, D23, D24, D25, D26: 1N4148_TS; D_SOD-123
H1, H2, H3: M2; MountingHole_2.2mm_M2
H7, H9, H10, H13, H14, H15: 3.5mm; MountingHole_3.5mm
K1, K2, K3, K4, K5, K6, K8, K9, K10, K11, K12, K13, K14, K15, K16, K17, K18, K19, K20, K21, K24, K25: SW_Push; SW_Choc_KLP12_Hotswap_Plated_1.00u
K7: EC-11; RotaryEncoder_EC11
K22: SW_Push; SW_Choc_KLP12_Hotswap_Plated_1.25u
K23: SW_MicroSwitches_Kailh_THT
K26: NS Joy-con; Joystick_NSJoy-con
L1, L2, L3, L4, L5, L6, L7, L8, L9, L10, L11, L12, L13, L14, L15, L16, L17, L18, L19, L20, L21, L22, L23: WS2812B; LED_SK6812MINI-E
RE1: MW; RotaryEncoder_MouseWheel
SYM1: Logo; OSHW-Symbol_8.9x8mm_SilkScreen
T1: TRRS_L; TRRS-PJ-320A
U1: MCU_Left; MCU_RP2040SuperMini_SMD

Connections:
5V-L: K26.6 (VCC), L1.1 (VDD), L2.1 (VDD), L3.1 (VDD), L4.1 (VDD), L5.1 (VDD), L6.1 (VDD), L7.1 (VDD), L8.1 (VDD), L9.1 (VDD), L10.1 (VDD), L11.1 (VDD), L12.1 (VDD), L13.1 (VDD), L14.1 (VDD), L15.1 (VDD), L16.1 (VDD), L17.1 (VDD), L18.1 (VDD), L19.1 (VDD), L20.1 (VDD), L21.1 (VDD), L22.1 (VDD), L23.1 (VDD), T1.1 (T/VCC), U1.1 (5V)
A1: RE1.A (CLK), U1.23 (GP13)
A2: K7.B (DT), U1.21 (GP11)
B1: RE1.B (DT), U1.22 (GP12)
B2: K7.A (CLK), U1.20 (GP10)
GND: K7.C (GND), K26.5 (GND), L1.3 (VSS), L2.3 (VSS), L3.3 (VSS), L4.3 (VSS), L5.3 (VSS), L6.3 (VSS), L7.3 (VSS), L8.3 (VSS), L9.3 (VSS), L10.3 (VSS), L11.3 (VSS), L12.3 (VSS), L13.3 (VSS), L14.3 (VSS), L15.3 (VSS), L16.3 (VSS), L17.3 (VSS), L18.3 (VSS), L19.3 (VSS), L20.3 (VSS), L21.3 (VSS), L22.3 (VSS), L23.3 (VSS), RE1.C (GND), T1.3 (R/GND), U1.2 (GND)
Left_data: T1.2 (R/SNL), U1.10 (GP0)
unnamed: D1.2, K1.1
unnamed: D2.2, K2.1
unnamed: D3.2, K3.1
unnamed: D4.2, K4.1
unnamed: D5.2, K5.1
unnamed: D6.2, K6.1
unnamed: D8.2, K8.1
unnamed: D9.2, K9.1
unnamed: D10.2, K10.1
unnamed: D11.2, K11.1
unnamed: D12.2, K12.1
unnamed: D13.2, K13.1
unnamed: D14.2, K14.1
unnamed: D15.2, K15.1
unnamed: D16.2, K16.1
unnamed: D17.2, K17.1
unnamed: D18.2, K18.1
unnamed: D19.2, K19.1
unnamed: D20.2, K20.1
unnamed: D21.2, K21.1
unnamed: D22.2, K22.2
unnamed: D24.2, K24.1
unnamed: D25.2, K25.1
unnamed: D7.2, K7.S2 (SW)
unnamed: D23.2, K23.2 (S2)
unnamed: D26.2, K26.3 (SW)
unnamed: L1.2 (DOUT), L2.4 (DIN)
unnamed: L2.2 (DOUT), L3.4 (DIN)
unnamed: L3.2 (DOUT), L4.4 (DIN)
unnamed: L4.2 (DOUT), L5.4 (DIN)
unnamed: L5.2 (DOUT), L6.4 (DIN)
unnamed: L6.2 (DOUT), L7.4 (DIN)
unnamed: L7.2 (DOUT), L8.4 (DIN)
unnamed: L8.2 (DOUT), L9.4 (DIN)
unnamed: L9.2 (DOUT), L10.4 (DIN)
unnamed: L10.2 (DOUT), L11.4 (DIN)
unnamed: L11.2 (DOUT), L12.4 (DIN)
unnamed: L12.2 (DOUT), L13.4 (DIN)
unnamed: L13.2 (DOUT), L14.4 (DIN)
unnamed: L14.2 (DOUT), L15.4 (DIN)
unnamed: L15.2 (DOUT), L16.4 (DIN)
unnamed: L16.2 (DOUT), L17.4 (DIN)
unnamed: L17.2 (DOUT), L18.4 (DIN)
unnamed: L18.2 (DOUT), L19.4 (DIN)
unnamed: L19.2 (DOUT), L20.4 (DIN)
unnamed: L20.2 (DOUT), L21.4 (DIN)
unnamed: L21.2 (DOUT), L22.4 (DIN)
unnamed: L22.2 (DOUT), L23.4 (DIN)
RGB-L: L1.4 (DIN), U1.11 (GP1)
X1: K26.1 (X/AD1), U1.4 (GP29)
Y1: K26.4 (Y/AD2), U1.5 (GP28)
col0: K1.2, K2.2, K3.2, U1.12 (GP2)
col1: K4.2, K5.2, K6.2, K7.S1 (GND), U1.13 (GP3)
col2: K8.2, K9.2, K10.2, K11.2, U1.14 (GP4)
col3: K12.2, K13.2, K14.2, U1.15 (GP5)
col4: K15.2, K16.2, K17.2, K18.2, U1.16 (GP6)
col5: K19.2, K20.2, K21.2, K22.1, U1.17 (GP7)
col6: K23.1 (S1), K24.2, K25.2, K26.2 (GND), U1.18 (GP8)
row0: D1.1, D4.1, D8.1, D12.1, D15.1, D19.1, D23.1, U1.6 (GP27)
row1: D2.1, D5.1, D9.1, D13.1, D16.1, D20.1, D24.1, U1.7 (GP26)
row2: D3.1, D6.1, D10.1, D14.1, D17.1, D21.1, D25.1, U1.8 (GP15)
row3: D7.1, D11.1, D18.1, D22.1, D26.1, U1.9 (GP14)
